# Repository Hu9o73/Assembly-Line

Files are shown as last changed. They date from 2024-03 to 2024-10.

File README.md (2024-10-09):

# Assembly Line

Projet Assembly Line : L'objectif étant de créer une machine fabricant des drones à la chaine.

Note: Par manque de fonds, le projet a été arrêté à la fin de la phase de conception. Le document UROP-PrésentationProjetComplet.pdf recense nos travaux.

Projet réalisé en collaboartion avec Théo Lissarague. Son profil GitHub peut être retrouvé dans la liste des contributeurs au projet.

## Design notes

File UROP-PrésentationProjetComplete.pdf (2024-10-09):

# UROP : Assembly Line

# Introduction

Des élèves du centre d'innovation (DVIC) du Pôle Universitaire Léonard de Vinci, à la Défense, ont pour objectif de développer un essaim de drones volants. Le développement de leur projet avançant à grands pas, ils ont désormais la nécessité de produire massivement leurs appareils.

L'option industrielle classique n'était pas viable. La quantité de drones à produire étant ridicule à l'échelle d'une usine spécialisée, et même si la quantité n'avait pas été un problème, cela aurait coûté très cher. Ils misent alors sur le développement d'une petite chaine de production, interne au centre, qui réduirait les coûts en plus d'être adaptée à leurs problématiques.

C’est pour répondre à ce besoin que nous avons pour objectif de développer une chaîne d'assemblage capable de produire massivement et sans efforts des drones roulants simples. Une fois la technologie développée pour ces drones simples, la chaine d'assemblage servira de base à une seconde version, modifiée pour produire les drones volants de l'essaim.

# Partie 1 : Le Drone

# Conception

Avant de se lancer dans la conception de la chaine d'assemblage, nous devions savoir quoi assembler. Le cahier des charges du drone était relativement court. Il nous fallait un drone roulant autonome dont la surface au sol ne dépassait pas quinze par quinze centimètres.

Les contraintes supplémentaires, nous nous les sommes imposés en pensant à ce que nous imposerait notre chaine d'assemblage.

La complexité d'une chaine d'assemblage varie grandement. En effet, encastrer une pièce dans une autre est simple. Mais si notre système est plus complexe que deux pièces de Lego®, la complexité de la chaine d'assemblage croît de façon exponentielle. Par exemple, l'ajout d'une simple vis peut impliquer la création d'un bras capable de s'aligner sur le pas de vis, poser la vis, puis changer d'outil pour la visser.

Bien que ce soit quelque chose qui est développable, notre mission est de produire des drones simples dans leur conception pour limiter au maximum la complexité de notre chaine d'assemblage. Nos travaux serviront de base pour développer une chaine plus complexe, adaptée aux drones volants.

Ainsi, nous avons fait le choix de limiter à deux le nombre de roues, car moins de roues c'est moins de moteurs, d'électronique et d'encastrements sur la chaine d'assemblage. La stabilité de notre drone sera assurée différemment. De plus, nous avons décidé de nous débarrasser des vis et d'assurer l'intégralité des liaisons par des systèmes de fixation rapide (clips).

Ne visant pas la performance sur ces petits drones, nous n'avons aucunement besoin qu'ils soient rapide. Ainsi, pour les contrôler plus facilement, nous faisons le choix de moteurs pas-à-pas pour actionner les roues, plutôt que les moteurs à courant continu standard. Les moteurs pas-àpas permettent un contrôle très précis en échange d'une vitesse plus lente.

# Electronique et PCB

Sachant dans quelle direction nous allons, nous décidons que le drone serait construit autour de
son PCB (Printed Circuit Board | Circuit Imprimé). Ainsi, nous commençons par cette étape
avec comme objectif de le rendre le plus petit possible.

Le drone serait dans un premier temps contrôlé par une carte de développement de type ESP32. Elles ne sont pas très cher, simple à programmer et s'adaptent largement à nos besoins tout en laissant place à d'éventuelles améliorations du drone par la suite.

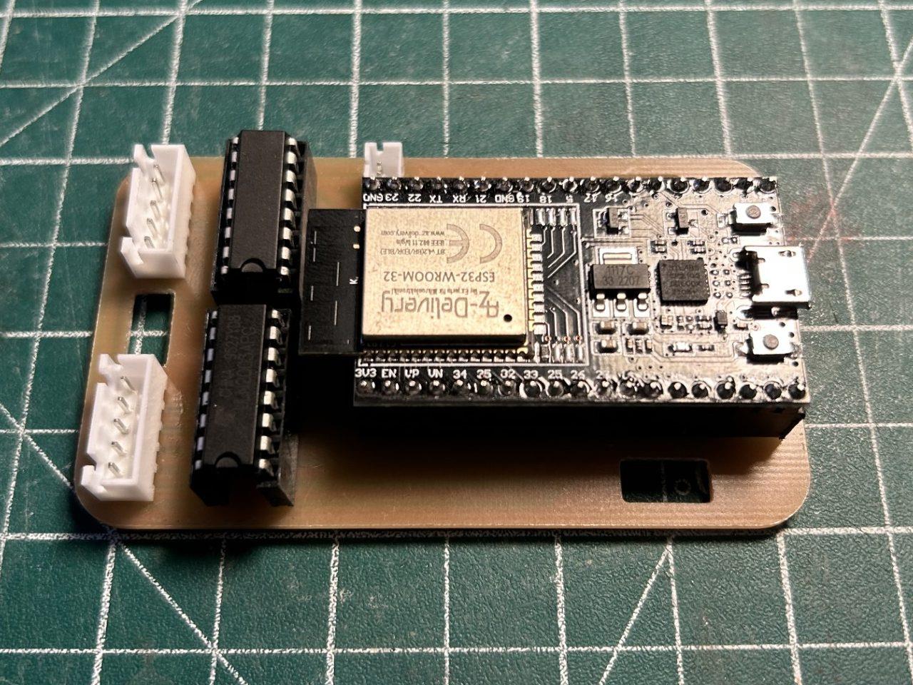
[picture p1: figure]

L'ESP32 (à droite), fixé sur le circuit imprimé de prototypage.

Dans le but de faire le drone le moins cher possible à la production, nous choisissons des moteurs pas-à-pas 28BYJ-48 en 5V. Ce sont les moteurs pas-à-pas de base, ils sont massivement produit, ne coûtent pas cher et sont simple à contrôler. De plus, après quelques tests, nous réalisons qu'ils tournent toujours avec une alimentation de 3.7V.

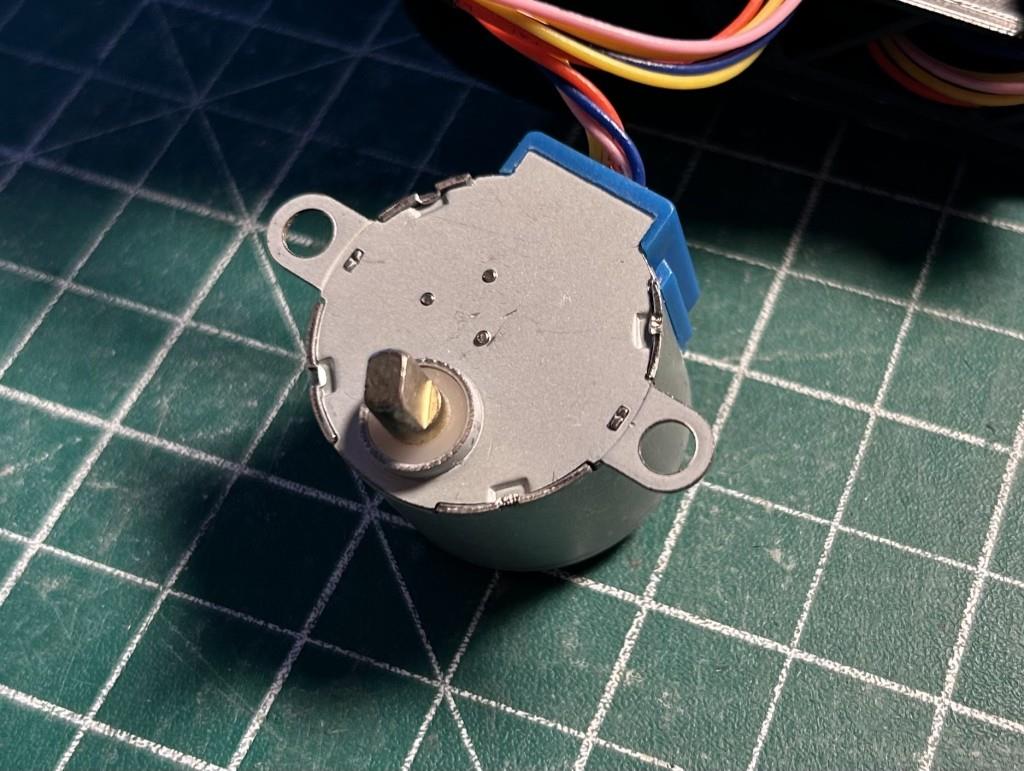
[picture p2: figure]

Un moteur pas-à-pas 28BYJ-48 utilisé sur le drone.

Nous faisons le choix d’alimenter notre drone à l’aide d'une batterie LiPo 3.7V. Nous économisons ainsi sur le plan financier et énergétique. En effet, pour une consommation de x ampères, notre drone sera 25% moins puissant avec une batterie en 3.7V plutôt que 5V, et par conséquent 25% moins énergivore.

Pour les contrôler, ils sont généralement livrés avec des drivers "UNL-2003". Ces derniers mesurent 3 centimètres par 3, il en faut un par moteur et par conséquent il serait bon de pouvoir s'en passer pour gagner de la place.

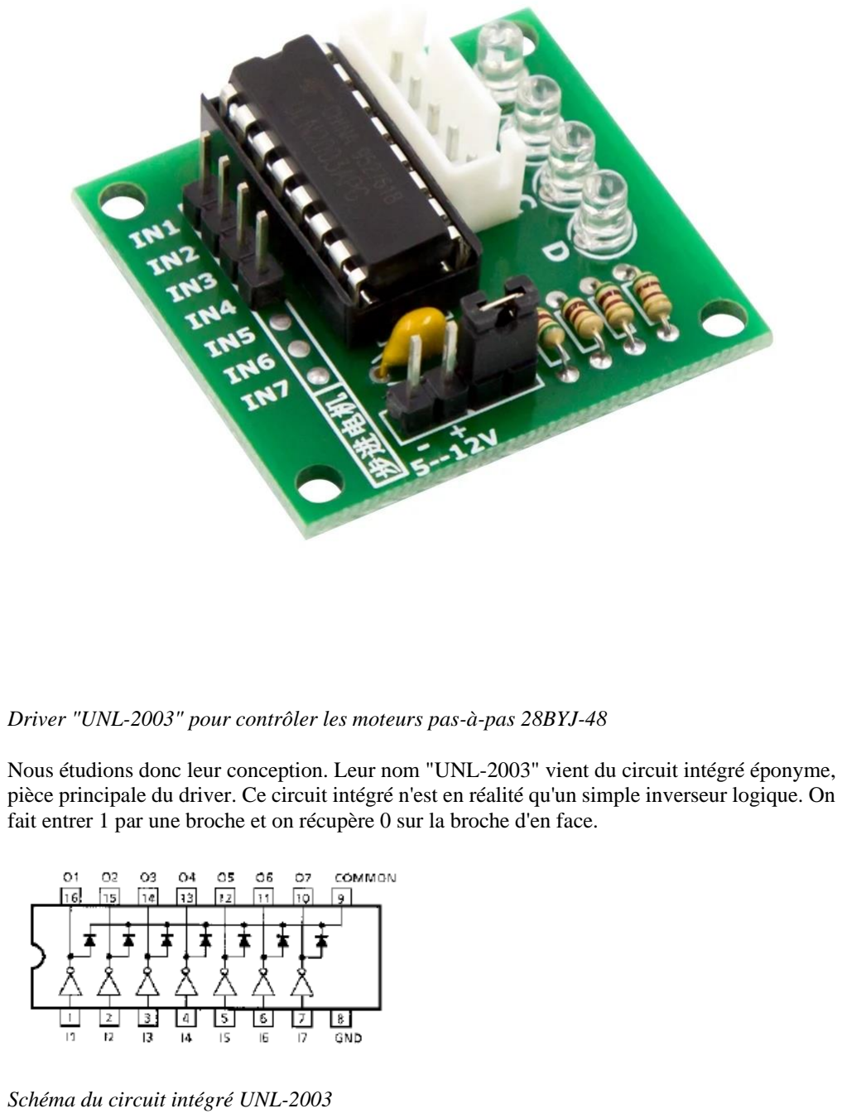
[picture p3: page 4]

Driver "UNL-2003" pour contrôler les moteurs pas-à-pas 28BYJ-48

Nous étudions donc leur conception. Leur nom "UNL-2003" vient du circuit intégré éponyme, pièce principale du driver. Ce circuit intégré n'est en réalité qu'un simple inverseur logique. On fait entrer 1 par une broche et on récupère 0 sur la broche d'en face.

Schéma du circuit intégré UNL-2003

Voyant un circuit intégré si simple, nous nous demandons pourquoi avoir besoin de tout le reste pour que le driver fonctionne. Par une simple étude du circuit imprimé du driver, nous concluons que hors du circuit intégré, le reste de le PCB du driver n'est utile qu'à l'allumage de LEDs pour avoir un retour visuel des ordres de contrôle envoyés au moteur. Nous décidons donc de ne garder de ce driver superflu que le circuit intégré.

Nous n'aurons ainsi qu'à commander les circuits intégrés à quelques centimes l'unité plutôt que le PCB dans son intégralité. Nous simplifions ainsi le circuit de notre drone et une nouvelle fois, nous réalisons des économies financières, de place et énergétiques (suppression des LEDs implique suppression de la consommation liées à ces dernières) !

Notre circuit, désormais simplifié au maximum, ne se résume qu'à une carte de développement ESP32, quelques connecteurs et deux circuits intégrés UNL-2003. Ces derniers ne disposant que de 7 couples de broches entrées/sorties, sachant qu'il en faut 4 par moteur, nous sommes contraints d'en utiliser 2. Remarque nous pourrions à l'avenir, chercher un circuit intégré similaire intégrant plus de broches, mais le drone n'étant pas l'objet principal de notre projet, pour gagner du temps sur le développement de la chaîne de production à proprement parler, nous n'avons pour l'heure pas cherché à l'optimiser à ce point.

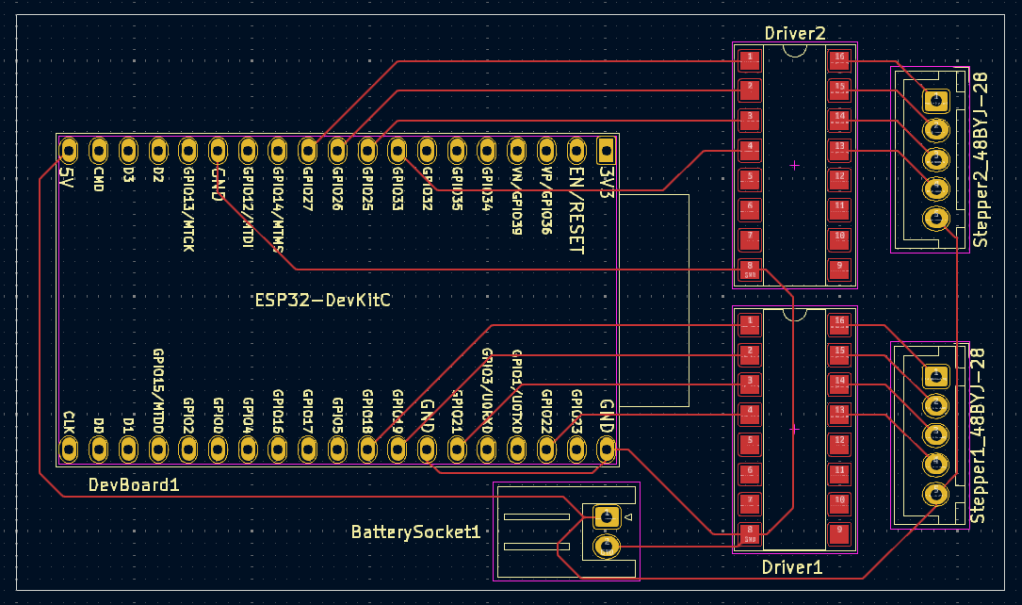
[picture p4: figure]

Schéma du PCB de notre drone : Le schéma du circuit est disponible sur le GitHub (https://github.com/theoliss/assembly_line/tree/main)

# CAD

Une fois le PCB déterminé et dont le prototype ait été fabriqué au sein même du DVIC, nous avons pu nous lancer sur le développement du drone. Pour simplifier l'assemblage nous avons supprimé d'éventuelles vis au profit d'un système d'accroche rapide pour le drone et le PCB et d'encastrement pour les moteurs.

Le drone sera constitué de trois couches. Une base sur laquelle siègent les accroches de notre système de fixation, qui traverseront tout le drone ; un étage intermédiaire destiné au maintien des moteurs latéraux; enfin, un étage supérieur, soutenu par une forêt de supports, sur lequel viendra se fixer notre PCB. La batterie viendra se glisser à l'arrière, dans un emplacement dédié, caché dans la forêt de supports.

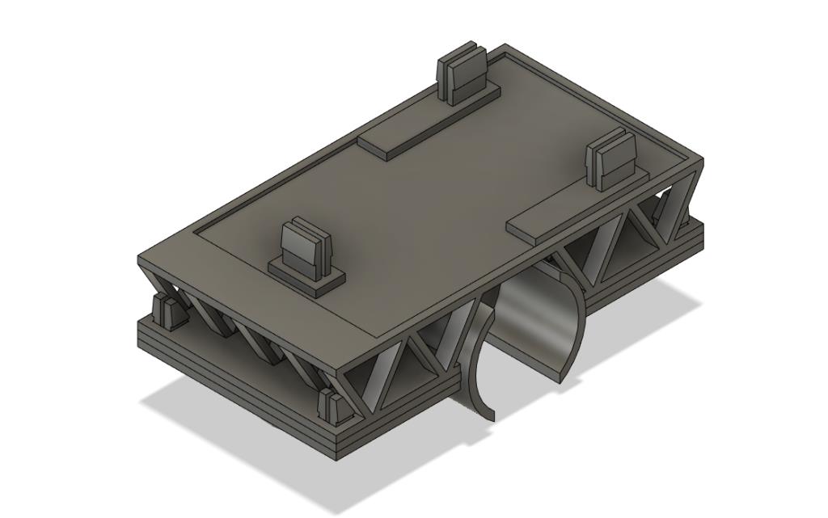
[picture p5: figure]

Structure du drone, les 3 parties assemblées, modélisée sur Fusion360, fichiers disponibles sur le GitHub (https://github.com/theoliss/assembly_line/tree/main)

# Partie 2 : La chaîne d'assemblage

# Conception

Le drone à assembler prêt, nous pouvions nous pencher sur la chaîne d'assemblage en ellemême. Dans un premier temps nous avons pensé à un système de tapis roulant, bacs à pièces et presses pour tout assembler. Cependant l'idée est de toujours penser au plus simple. Le but est de pouvoir adapter notre chaîne à différents types de drones facilement. Ainsi nous nous sommes demandé comment réduire le nombre d'éléments pour faciliter l'adaptabilité.

C'est pourquoi nous nous sommes orientés vers un bras robotisé. Très versatile, il nous permettra de réaliser une floppée de tâches de différentes natures : attraper, poser, enfoncer, visser (soyons fou !).

Pour gagner du temps nous nous sommes basés sur le bras open source de BCN3D, lui-même basé sur un autre bras open source. Après lui avoir apporté quelques modifications pour qu'il réponde à nous besoins, nous l'avons mis sur rail pour ajouter un axe de mobilité, étendant le champ des possibles.

# Le bras

Comme dit plus haut, la base de notre bras est le Moveo de BCN3D (bras open-source) dont voici le GitHub. (https://github.com/BCN3D/BCN3D-Moveo) Après quelques calculs, nous décidons de changer les moteurs pas-à-pas pour des plus puissants, afin qu'il soit en mesure de réaliser les tâches qui lui incomberont. Ce changement impliqua un recalcul de la mécanique du bras, ainsi que de la puissance totale nécessaire pour faire fonctionner la chaîne. (cf. document « CalculsCouples »)

Par la suite, nous avons conçu son rail, le bras se déplaçant latéralement sur environ quatrevingts centimètres, tracté par un moteur pas-à-pas supplémentaire.

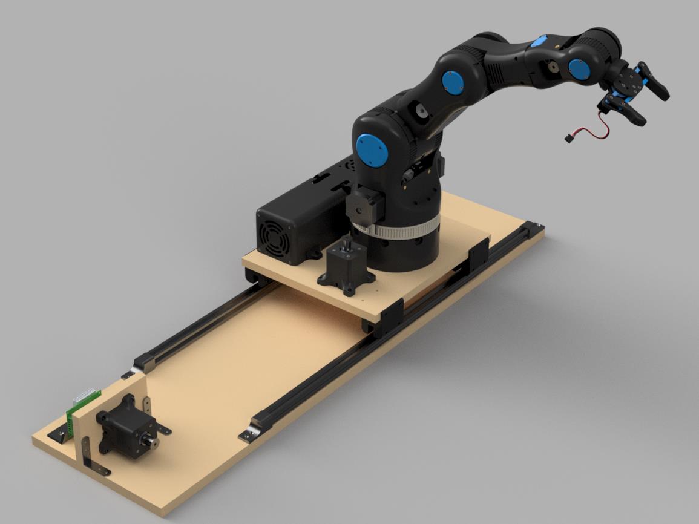
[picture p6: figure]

Le MOVEO modifié sur son rail.

Après avoir effectué les calculs mécaniques et électroniques mentionnés plus haut et disponibles dans des documents PDF sur le GitHub, (https://github.com/theoliss/assembly_line/tree/main) nous jetons nos dévolus sur les moteurs NEMA suivants :

Référence | Type | Couple | Quantité
14HS20-1504S | NEMA 14 | 40 Ncm | 1
17HS13-0404S1 | NEMA 17 | 26 Ncm | 1
17HS19-1684S-PG5 NEMA 17 | Engrenages 5:1 52 Ncm (moteur seul) 1
17HE24-2104S | NEMA 17 | 60 Ncm | 2
23HE22-2804S | NEMA 23 | 126 Ncm | 2

Tableau des moteurs utilisés pour la fabrication du bras.

Concernant l'électronique, le bras sera contrôlé par une carte de développement fonctionnant avec une puce ATMega (un équivalent Arduino MEGA). La carte contrôlera les sept drivers TB6560, le tout étant alimenté par une alimentation de 24V pour 600 watts. Voici un extrait du schéma, le schéma complet et les évaluations de consommation étant disponibles sur le GitHub. (https://github.com/theoliss/assembly_line/tree/main)

Nous sommes ici contraint de changer de drivers car contrairement aux petits moteurs du drone, les NEMA sont des moteurs bien plus puissant. L'intensité nécessaire peut flirter avec les 3 ampères pour les NEMA 23 ! Bien au delà de la limite de l'intensité délivrable par une carte de développement (200mA pour l'Arduino MEGA, soit 15 fois moins). D'où la nécessité de penser à notre alimentation et ses limites, ainsi qu'à la mise en place de drivers adaptés. Ici, les TB6560 sont conçu pour supporter jusqu'à 3A, nous permettant de travailler avec les NEMA 14, 17 et 23 que nous comptons utiliser.

Nous avons choisi les NEMA pour leur rapport qualité/prix et leur disponibilité sur le marché (en plus du fait qu'ils respectent nos contraintes).

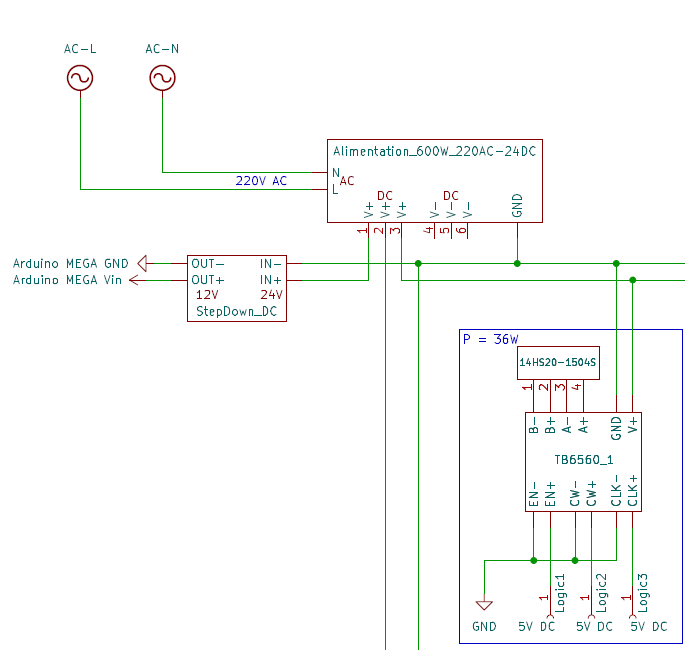
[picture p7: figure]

Extrait du schéma. Les autres blocs moteurs + drivers sont connectés de la même façon, tous en dérivation.

# Sources :

GitHub du projet : GitHub - Assembly Line (https://github.com/theoliss/assembly_line/tree/main)

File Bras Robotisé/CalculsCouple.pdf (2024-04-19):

BONNELL Hugo

# UROP - Assembly Line

### Calculs couples moteurs

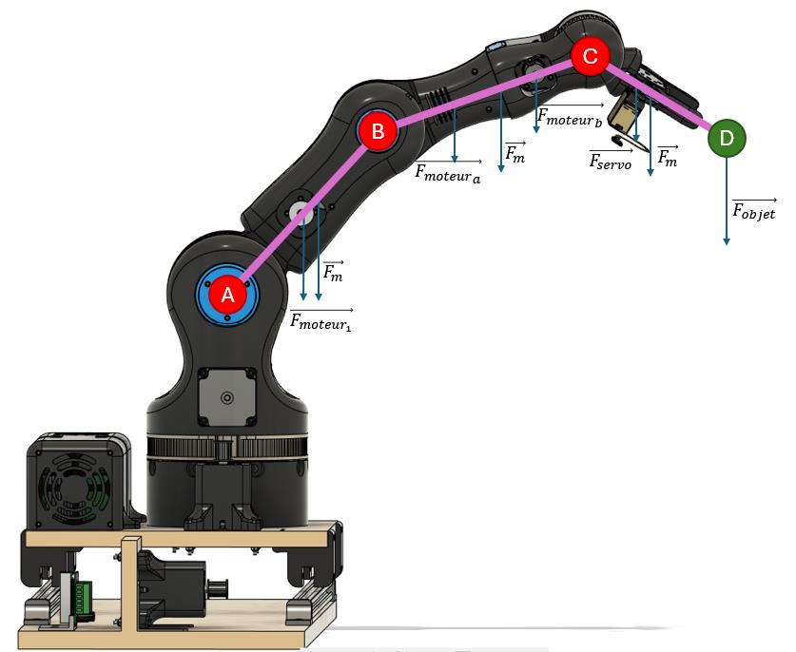
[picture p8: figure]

# Introduction

Ce document recense les calculs effectués pour déterminer les couples nécessaires des moteurs pas-à-pas dans le bras de la chaîne d’assemblage. Pour effectuer ces calculs, nous considérons le bras dans sa position la plus contraignante pour les moteurs, c’est-à-dire complètement « détendu » parallèle au sol.
C’est en effet dans cette position que le couple de maintient des moteurs devra être le plus important pour maintenir le bras dans un état statique.
Si les couples des moteurs dépassent les valeurs trouvées, alors en plus de maintenir le bras statique dans cette position, les moteurs seront également capable d’actionner le bras.
Nous considérons que le bras doit pouvoir manipuler un objet d’un poids de 400g au maximum afin d’avoir une (très) confortable marge pour l’assemblage de notre drone, où de changer l’objet de la chaine d’assemblage plus aisément.

# Section A : Choix des moteurs pas-à-pas

## Schémas :

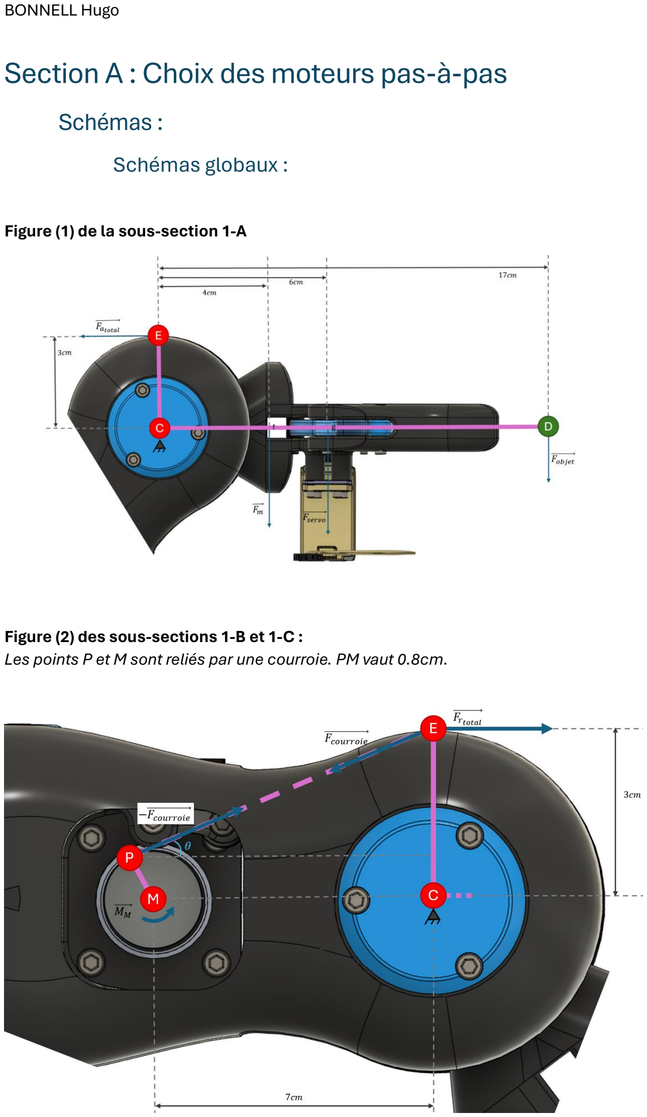
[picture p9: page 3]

### Schémas globaux :

Figure (1) de la sous-section 1-A

Figure (2) des sous-sections 1-B et 1-C :
Les points P et M sont reliés par une courroie. PM vaut 0.8cm.

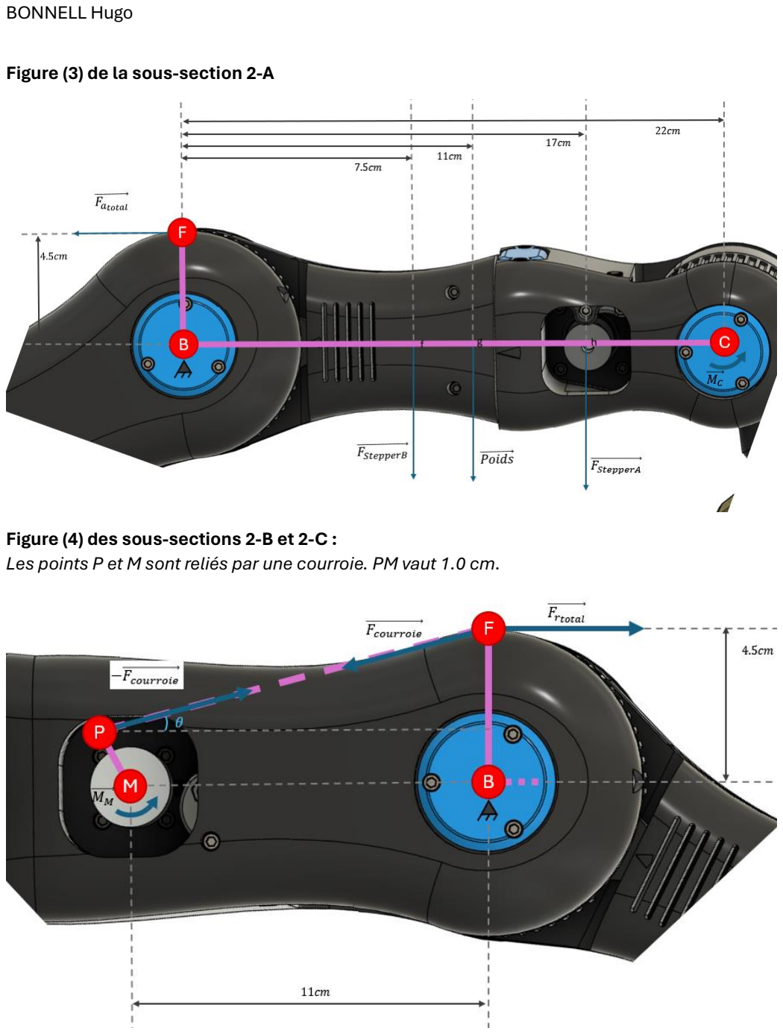
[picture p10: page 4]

Figure (3) de la sous-section 2-A

Figure (4) des sous-sections 2-B et 2-C :
Les points P et M sont reliés par une courroie. PM vaut 1.0 cm.

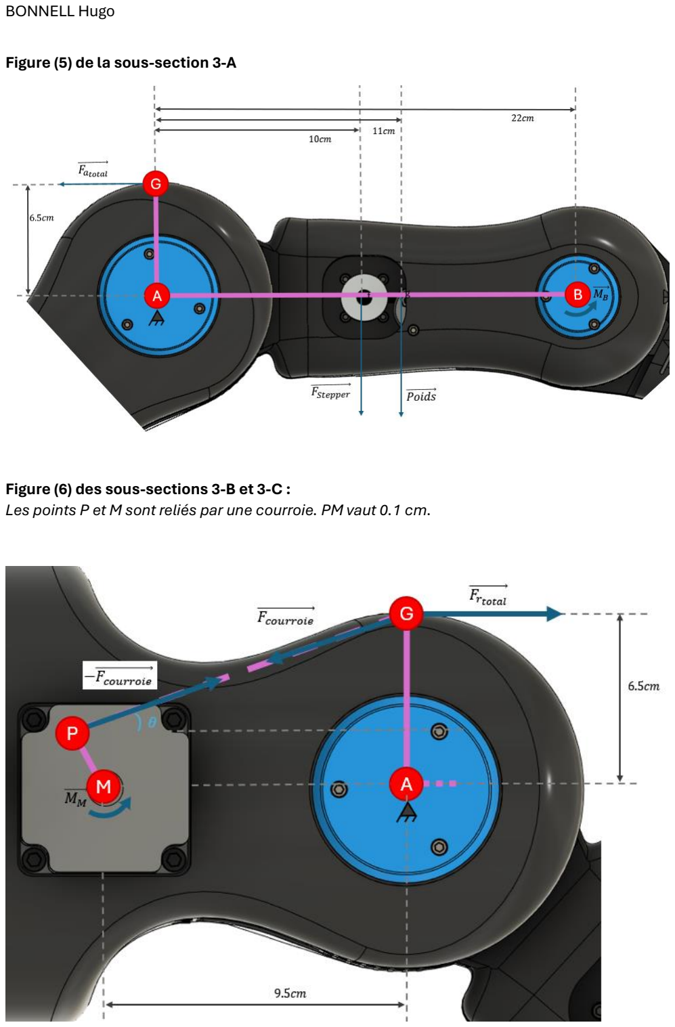
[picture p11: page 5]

Figure (5) de la sous-section 3-A

Figure (6) des sous-sections 3-B et 3-C :
Les points P et M sont reliés par une courroie. PM vaut 0.1 cm.

### Schémas simplifiés :

Figure (7) – Sous-section 1-A

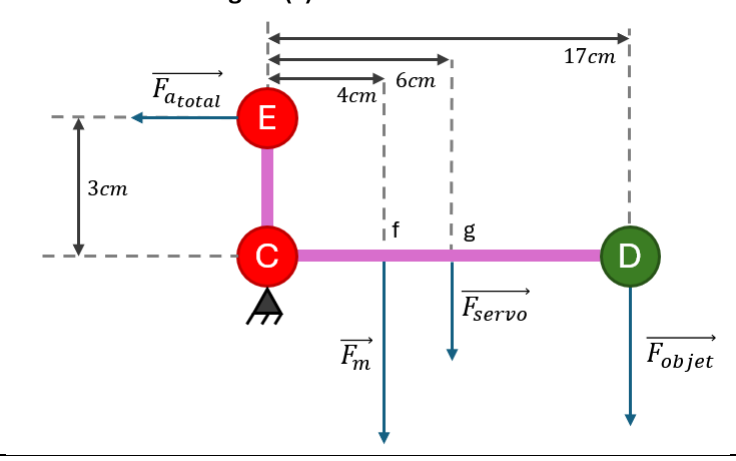
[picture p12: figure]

Figure (8) – Sous-section 1-B

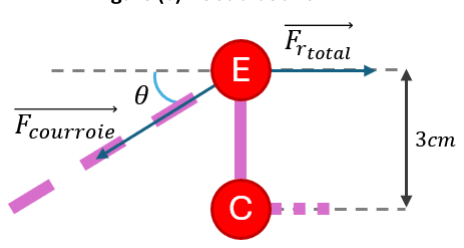
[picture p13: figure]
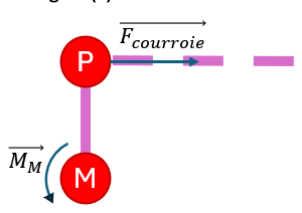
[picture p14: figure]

Figure (9) – Sous-section 1-C

Figure (10) – Sous-section 2-A

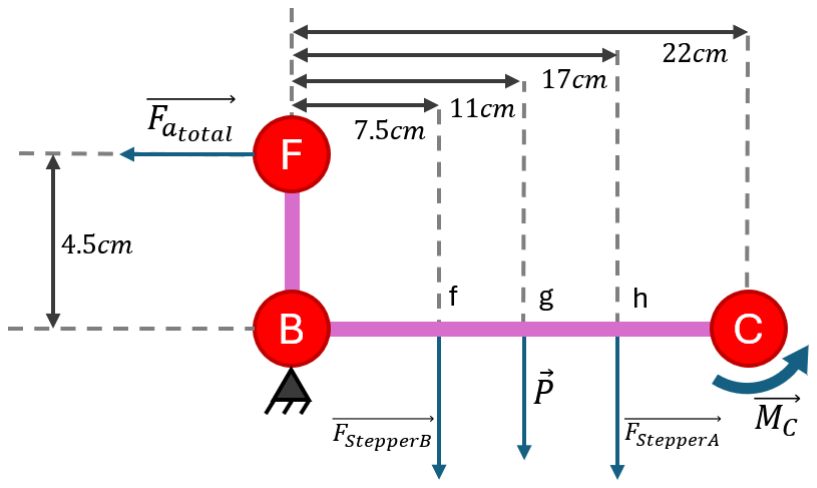
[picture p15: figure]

Figure (11) – Sous-section 2-B

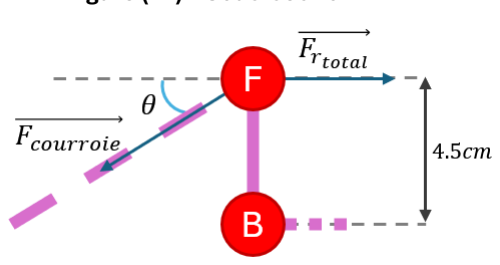
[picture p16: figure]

Figure (12) – Sous-section 2-C

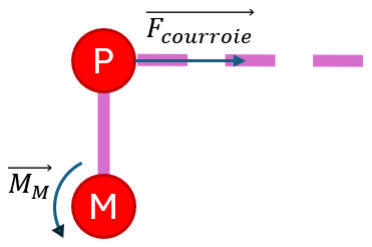
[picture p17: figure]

Figure (13) – Sous-section 3-A

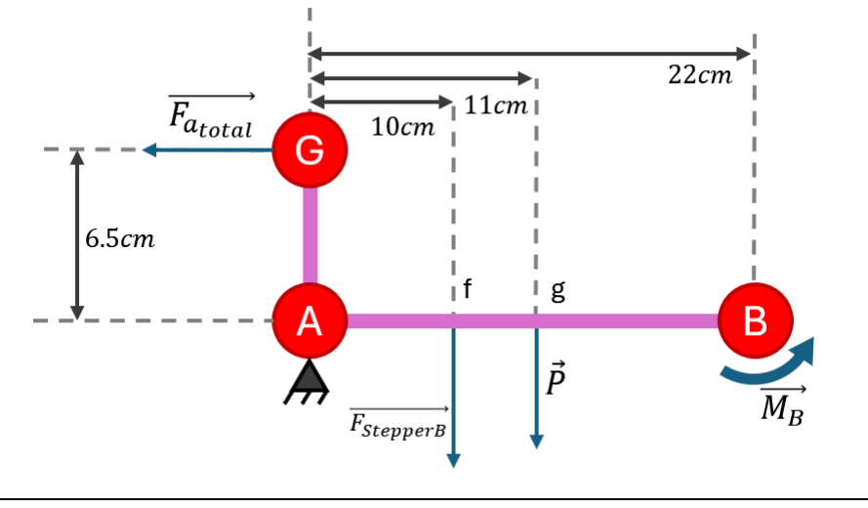
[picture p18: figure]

Figure (14) – Sous-section 3-B

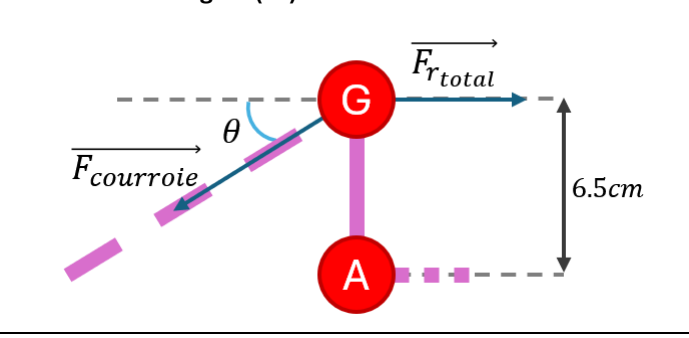
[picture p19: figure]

Figure (15) – Sous-section 3-C

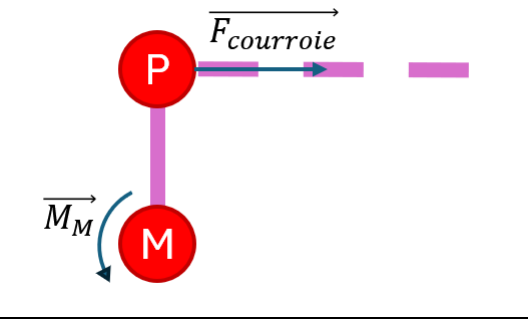
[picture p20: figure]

## Calculs Section 1 :

### Déterminer θ :

Par simple déduction trigonométrique, grâce à la figure (2) on obtient :

θ = arctan (

3 − 0,8
7

) = 0,30 rad

### Déterminer le couple du moteur M de cette section :

En appliquant le théorème des moments statiques :

SOUS-SECTION 1-A :

∑M⃗ (C, Fext ⃗⃗⃗⃗⃗⃗⃗ ) = CE⃗ ∧ Fatotal ⃗⃗⃗⃗⃗⃗⃗⃗ + Cf⃗⃗⃗ ∧ Fm
⃗⃗⃗⃗ + Cg⃗ ∧ Fservo

⃗⃗⃗⃗⃗⃗⃗ + CD⃗⃗⃗ ∧ Fobjet ⃗⃗⃗⃗⃗⃗⃗⃗⃗

- ∑ M⃗ (C, Fext ⃗⃗⃗⃗⃗⃗⃗ ) = 0,03y ∧ (−Fatotal)x + 0,04x ∧ (−Fm)y + 0,06x ∧ (−Fservo)y + 0,17x × (−Fobjet)y
- 0,03Fatotal = (0,04 × 0,150 + 0,06 × 0,060 + 0,17 × 0,400) × 9,81
- Fatotal ≅ 25N
SOUS-SECTION 1-B :

Sachant ‖Fatotal

⃗⃗⃗⃗⃗⃗⃗⃗⃗⃗ ‖ = ‖Frtotal

⃗⃗⃗⃗⃗⃗⃗ ‖ :

∑M⃗ (C, Fext ⃗⃗⃗⃗⃗⃗⃗ ) = CE⃗ ∧ Frtotal ⃗⃗⃗⃗⃗⃗⃗⃗⃗⃗⃗⃗ + CE⃗ ∧ Fcouroie ⃗⃗⃗⃗⃗⃗⃗⃗⃗⃗

- ∑ M⃗ (C, Fext ⃗⃗⃗⃗⃗⃗⃗ ) = 0,03y ∧ Frtotal

⃗⃗⃗⃗⃗⃗⃗⃗⃗⃗⃗⃗ + 0,03y ∧ Fcouroie

⃗⃗⃗⃗⃗⃗⃗⃗⃗⃗

- ∑ M⃗ (C, Fext ⃗⃗⃗⃗⃗⃗⃗ ) = 0,03y ∧ Frtotal

⃗⃗⃗⃗⃗⃗⃗⃗⃗⃗⃗ + 0,03y ∧ (

− cos(θ)Fcouroie

− sin(θ)Fcouroie
0

)

- ∑ M⃗ (C, Fext ⃗⃗⃗⃗⃗⃗⃗ ) = 0,03y ∧ (

Frtotal
0
0

) + 0,03y ∧ (

− cos(θ)Fcouroie

− sin(θ) Fcouroie
0

)

- ∑ M⃗ (C, Fext ⃗⃗⃗⃗⃗⃗⃗ ) = (−0,03 × Frtotal + 0,03 × cos(θ) Fcouroie)z

Or : ∑ M⃗ (C, Fext ⃗⃗⃗⃗⃗⃗⃗ ) = 0 d’où: Frtotal = cos(θ) Fcouroie (= Fatotal) Fcouroie =

Fatotal
cos(θ)
SOUS-SECTION 1-C :

∑M⃗ (M, Fext ⃗⃗⃗⃗⃗⃗ ) = MM ⃗⃗⃗⃗ + MP ⃗⃗⃗ ∧ Fcouroie

⃗⃗⃗⃗⃗⃗⃗⃗⃗⃗⃗⃗ = 0

|MM

⃗⃗⃗⃗⃗⃗ | = |0,008x ∧

Fatotal
cos(θ)
y | = 0,008 ×

25
cos (0,300 rad)

= 0,21 Nm

## Choix du moteur Section 1 :

Pour maintenir un objet de 400g il nous faudrait un moteur de couple 21 Ncm. Ainsi, si nous voulons le soulever, on déduit qu’il nous faut un moteur plus puissant que 21Ncm.
Nos contraintes pour ce moteur deviennent les suivantes :
Type : | Moteur pas-à-pas
Dimensions (L*l*h) : | 35mm * 35mm * ∞ | Format NEMA14
Couple : | Min : 21N ∙ cm

On choisira donc le moteur suivant :
Type : | Pas-à-pas | NEMA 14
Référence : | 14HS20-1504S
Couple : | 40 N × cm
Poids : | 0.35kg
Tension nominale : | 4.2 V
Intensité par phase : | 1.5 A
Résistance/phase : | 2.8 ohms
Dimensions : | 35mm*35mm*52mm
Diamètre de l’arbre : | 5mm
Pas : | 1,8°
Connexions : | A+ | Noir A- | Vert B+ | Rouge B- | Bleu
Revendeur : | StepperOnline
Lien : | https://www.omc-stepperonline.com/fr/nema-14-bipolaire-1-8deg-40ncm-56-7oz-in-1-5a-4-2v-35x35x52mm-4-fils-14hs20-1504s

Note : Il existe un autre modèle de NEMA14 ayant pour couple 23Ncm. Par sécurité, il vaut mieux prendre de la marge en prenant le modèle du dessus (celui choisi).

## Calculs Section 2 :

### Déterminer θ :

Par simple déduction trigonométrique, grâce à la figure (4) on obtient :

θ = arctan (

4.5 − 1.0
11 ) = 0,308 rad

### Déterminer le couple du moteur M de cette section :

En appliquant le théorème des moments statiques : SOUS-SECTION 2-A :

∑M⃗ (B, Fext ⃗⃗⃗⃗⃗⃗⃗ ) = BF⃗ | ∧ Fatotal
⃗⃗⃗⃗⃗⃗⃗⃗⃗⃗⃗⃗ + Bf⃗ ∧ FStepperB ⃗⃗⃗⃗⃗⃗⃗⃗⃗⃗⃗⃗⃗⃗⃗⃗ + Bg⃗ | ∧ P⃗ + B⃗ℎ ∧ FStepperA ⃗⃗⃗⃗⃗⃗⃗⃗⃗⃗⃗⃗⃗⃗ + Mc
⃗
- ∑ M⃗ (B, Fext ⃗⃗⃗⃗⃗⃗⃗ ) = 0,045y ∧ (−Fatotal)x + 0,075x ∧ (−0,300 × 9,81)y + 0,11x ∧ (−0,200 × 9,81)y + 0,17x ∧ (−0,350 × 9,81)y + (0,26 × 0,150 + 0,28 × 0,060 + 0,39 × 0,400) × 9,81
- 0,045Fatotal = 0,075 × 2,943 + 0,11 × 1,962 + 0,17 × 3,4335 + 2,08 = 3,1
- Fatotal ≅ 69N
SOUS-SECTION 2-B :

Sachant ‖Fatotal

⃗⃗⃗⃗⃗⃗⃗⃗⃗⃗ ‖ = ‖Frtotal

⃗⃗⃗⃗⃗⃗⃗ ‖ :

∑M⃗ (B, Fext ⃗⃗⃗⃗⃗⃗⃗ ) = BF⃗ | ∧ Frtotal
⃗⃗⃗⃗⃗⃗⃗⃗⃗⃗⃗⃗ + BF⃗ | ∧ Fcouroie

⃗⃗⃗⃗⃗⃗⃗⃗⃗⃗⃗

- ∑ M⃗ (B, Fext ⃗⃗⃗⃗⃗⃗⃗ ) = 0,045y ∧ Frtotal

⃗⃗⃗⃗⃗⃗⃗⃗⃗⃗⃗⃗ + 0,045y ∧ Fcouroie

⃗⃗⃗⃗⃗⃗⃗⃗⃗⃗⃗⃗

- ∑ M⃗ (B, Fext ⃗⃗⃗⃗⃗⃗⃗ ) = 0,045y ∧ Frtotal

⃗⃗⃗⃗⃗⃗⃗⃗⃗⃗⃗ + 0,045y ∧ (

− cos(θ) Fcouroie

− sin(θ) Fcouroie
0

)

- ∑ M⃗ (B, Fext ⃗⃗⃗⃗⃗⃗⃗ ) = 0,045y ∧ (

Frtotal
0
0

) + 0,045y ∧ (

− cos(θ) Fcouroie

− sin(θ)Fcouroie
0

)

- ∑ M⃗ (B, Fext ⃗⃗⃗⃗⃗⃗⃗ ) = (−0,045 × Frtotal + 0,045 × cos(θ) Fcouroie)z

Or : ∑ M⃗ (B, Fext ⃗⃗⃗⃗⃗⃗⃗ ) = 0 d’où: Frtotal = cos(θ) Fcouroie (= Fatotal) Fcouroie =

Fatotal
cos(θ)
SOUS-SECTION 2-C :

∑M⃗ (M, Fext ⃗⃗⃗⃗⃗⃗ ) = MM ⃗⃗⃗⃗ + MP ⃗⃗⃗ ∧ Fcouroie

⃗⃗⃗⃗⃗⃗⃗⃗⃗⃗⃗⃗ = 0

|MM

⃗⃗⃗⃗⃗⃗ | = |0,01x ∧

Fatotal
cos(θ)
y | = 0,01 ×

69
cos (0,308 rad)

= 0,72 Nm

## Choix du moteur Section 2 :

Nos contraintes pour ce moteur deviennent les suivantes :
Type : | Moteur pas-à-pas
Dimensions (L*l*h) : | 42mm * 42mm * 48mm | Format NEMA17
Couple : | Min : 72 N ∙ cm

On choisira donc le moteur suivant (moteur à engrenages !) :
Type : | Pas-à-pas | NEMA 17
Référence : | 17HS19-1684S-PG5
Couple avant boite d’engrenages : | 52 N × cm
Rapport de la boite d’engrenages : | 5.18 : 1
Couple de sortie : | 242 N ∙ cm
Poids : | 0.52kg
Tension nominale : | 3 V
Intensité par phase : | 1.68 A
Résistance/phase : | 1.8 ohms
Dimensions : | 42mm*42mm*48mm
Diamètre de l’arbre : | 8mm
Pas : | 0,35°
Connexions : | A+ | Noir A- | Vert B+ | Rouge B- | Bleu
Revendeur : | StepperOnline
Lien : | https://www.omc-stepperonline.com/fr/nema-17-moteur-pas-a-pas-bipolaire-l-48mm-w-rapport-d-engrenage-5-1-boite-de-vitesses-planetaire-17hs19-1684s-pg5

Note :
Les moteurs NEMA 17 n’atteignant pas un couple suffisant, nous nous rabattons sur un pas-àpas avec système d’engrenages. En réduisant ainsi la vitesse de rotation, nous augmentons le couple.
Bien que ce modèle ait un couple dépassant largement notre besoin, il remplit notre critère de dimension (Format NEMA 17 et 48mm de profondeur) et de couple.

## Calculs Section 3 :

### Déterminer θ :

Par simple déduction trigonométrique, grâce à la figure (6) on obtient :

θ = arctan (

6.5 − 1
9,5

) = 0,525 rad

### Déterminer le couple du moteur M de cette section :

En appliquant le théorème des moments statiques : SOUS-SECTION 3-A :

∑M⃗ (A, Fext ⃗⃗⃗⃗⃗⃗⃗ ) = AG⃗ ∧ Fatotal ⃗⃗⃗⃗⃗⃗⃗ + Af⃗ ∧ FStepper ⃗⃗⃗⃗⃗⃗⃗⃗⃗⃗ + Ag⃗ ∧ P⃗ + Mc ⃗

- ∑ M⃗ (A, Fext ⃗⃗⃗⃗⃗⃗⃗ ) = 0,065y ∧ (−Fatotal)x + 0,1x ∧ (−0,520 × 9,81)y + 0,11x ∧
(−0,200 × 9,81)y + (0,48 × 0,150 + 0,50 × 0,060 + 0,61 × 0,400 + 0,295 × 0,300 + 0,33 × 0,200 + 0,39 × 0,350) × 9,81
- 0,065Fatotal = 0,1 × 5,10 + 0,11 × 1,962 + 6,25 ≅ 7,0
- Fatotal ≅ 108N
SOUS-SECTION 3-B :

Sachant ‖Fatotal

⃗⃗⃗⃗⃗⃗⃗⃗⃗⃗ ‖ = ‖Frtotal

⃗⃗⃗⃗⃗⃗⃗ ‖ :

∑M⃗ (A, Fext ⃗⃗⃗⃗⃗⃗⃗ ) = AG⃗ | ∧ Frtotal
⃗⃗⃗⃗⃗⃗⃗⃗⃗⃗⃗⃗ + AG⃗ | ∧ Fcouroie
⃗⃗⃗⃗⃗⃗⃗⃗⃗⃗
- ∑ M⃗ (A, Fext ⃗⃗⃗⃗⃗⃗⃗ ) = 0,065y ∧ Frtotal

⃗⃗⃗⃗⃗⃗⃗⃗⃗⃗⃗⃗ + 0,065y ∧ Fcouroie

⃗⃗⃗⃗⃗⃗⃗⃗⃗⃗

- ∑ M⃗ (A, Fext ⃗⃗⃗⃗⃗⃗⃗ ) = 0,065y ∧ Frtotal

⃗⃗⃗⃗⃗⃗⃗⃗⃗⃗⃗ + 0,065y ∧ (

− cos(θ)Fcouroie

− sin(θ) Fcouroie
0

)

- ∑ M⃗ (A, Fext ⃗⃗⃗⃗⃗⃗⃗ ) = 0,065y ∧ (

Frtotal
0
0

) + 0,065y ∧ (

− cos(θ) Fcouroie

− sin(θ) Fcouroie
0

)

- ∑ M⃗ (A, Fext ⃗⃗⃗⃗⃗⃗⃗ ) = (−0,065 × Frtotal + 0,065 × cos(θ)Fcouroie)z

Or : ∑ M⃗ (A, Fext ⃗⃗⃗⃗⃗⃗⃗ ) = 0 d’où: Frtotal = cos(θ)Fcouroie (= Fatotal) Fcouroie =

Fatotal
cos(θ)
SOUS-SECTION 3-C :

∑M⃗ (M, Fext ⃗⃗⃗⃗⃗⃗ ) = MM ⃗⃗⃗⃗ + MP ⃗⃗⃗ ∧ Fcouroie

⃗⃗⃗⃗⃗⃗⃗⃗⃗⃗⃗⃗ = 0

|MM

⃗⃗⃗⃗⃗⃗ | = |0,008x ∧

Fatotal
cos(θ)
y | = 0,01 ×

108
cos (0,525 rad)

= 1.25 Nm

## Choix du moteur Section 3 :

Nos contraintes pour ce moteur deviennent les suivantes :
Type : | Moteur pas-à-pas
Dimensions (L*l*h) : | 57mm * 57mm * ∞ | Format NEMA23
Couple : | Min : 125 N ∙ cm

Les moteurs NEMA 17 n’atteignent pas un couple de 125 N ∙ cm. Ainsi, nous allons en installer deux, fonctionnant face à face et de façon symétrique pour additionner leurs couples. Ainsi, nous cherchons deux exemplaires d’un moteur NEMA 23 de couple 62,5 N ∙ cm au minimum !

Type : | Pas-à-pas | NEMA 23
Référence : | 23HE22-2804S
Couple : | 126 N × cm
Poids : | 0.70 kg
Tension nominale : | 2.52 V
Intensité par phase : | 2.8 A
Résistance/phase : | 0.9 ohms
Dimensions : | 57mm*57mm*56mm
Diamètre de l’arbre : | 6.35mm
Pas : | 1,8°
Connexions : | A+ | Noir A- | Vert B+ | Rouge B- | Bleu
Revendeur : | StepperOnline
Lien : | https://www.omc-stepperonline.com/fr/e-serie-nema-23-moteur-pas-a-pas-bipolar-1-8deg-1-26-nm-178-04oz-in-2-8a-57x57x56mm-4-fils-23he22-2804s

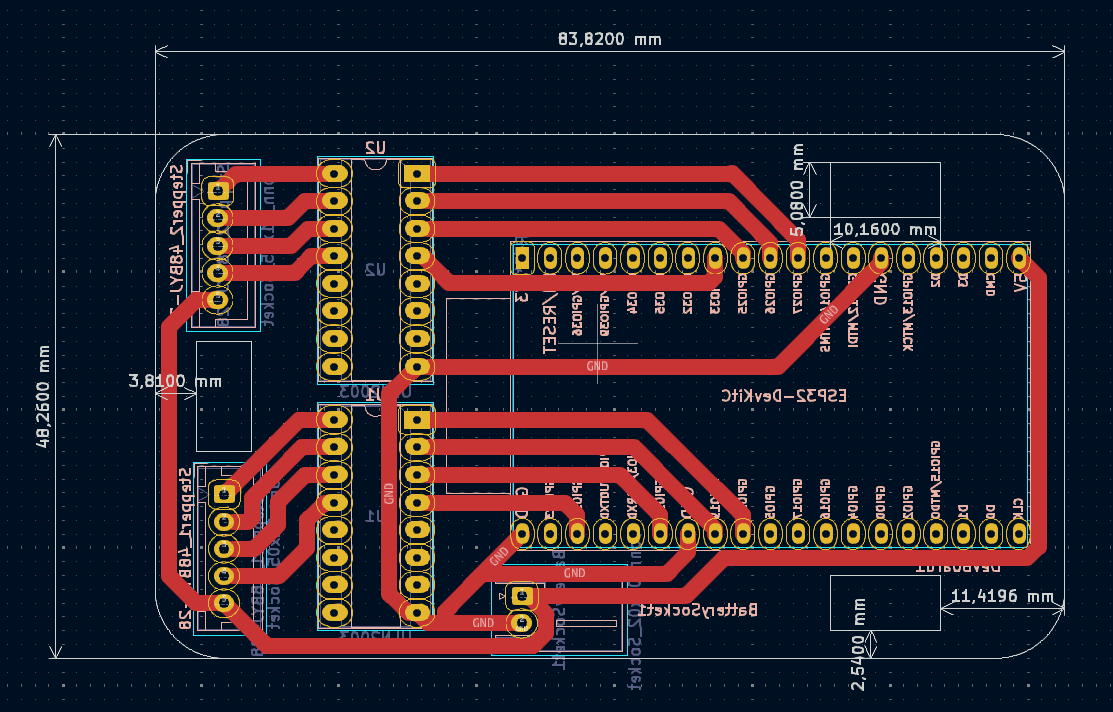
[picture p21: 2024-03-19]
Drone/Electronique/PDF et images/screen_PCB_Drone_THT.png

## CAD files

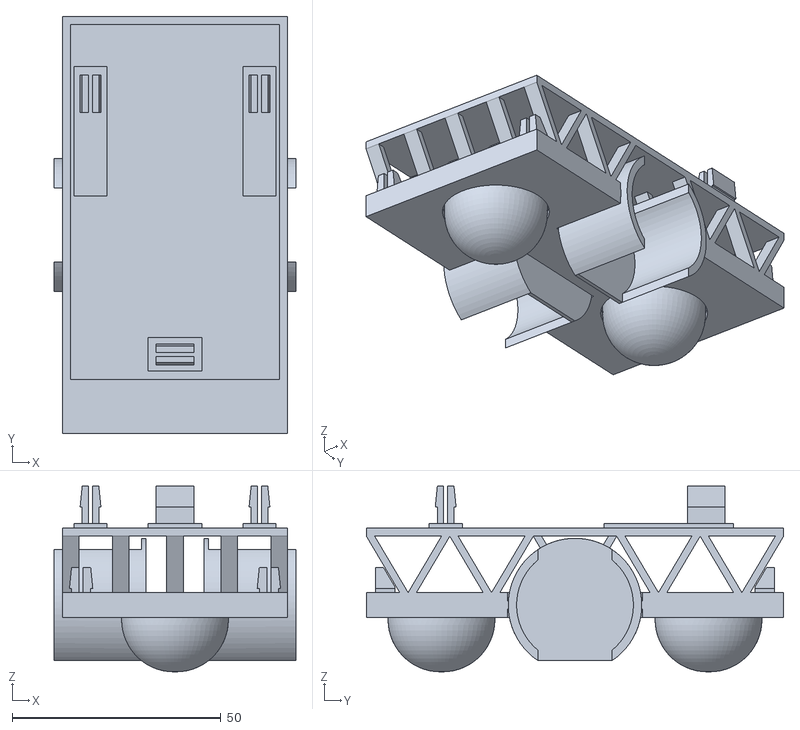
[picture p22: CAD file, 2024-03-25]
Drone/CAD/CAD_Drone/DroneFull.stl
58.0 x 100.0 x 44.5

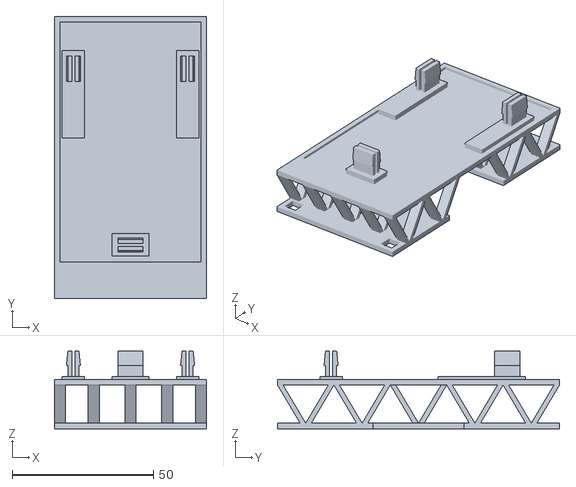
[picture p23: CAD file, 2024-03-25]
Drone/CAD/CAD_Drone/DroneTop.stl
54.0 x 100.0 x 27.5

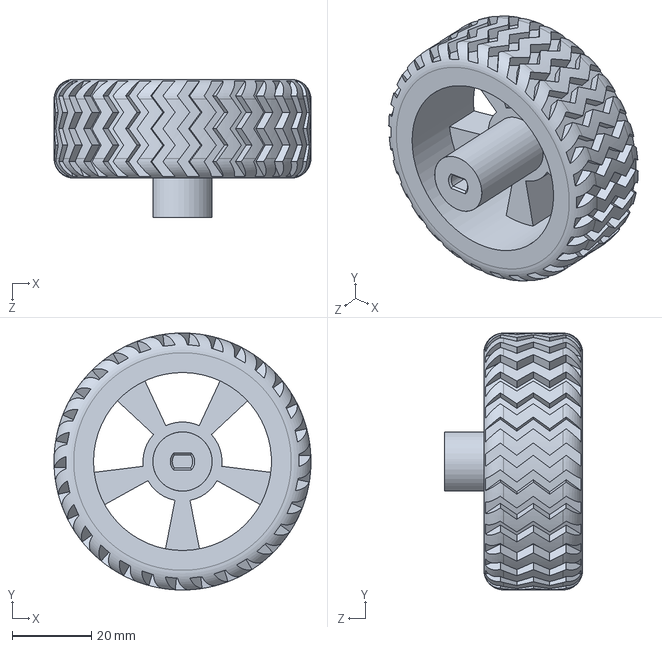
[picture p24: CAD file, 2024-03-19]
Drone/CAD/Roues.SLDPRT
65.0 x 65.0 x 35.0 mm

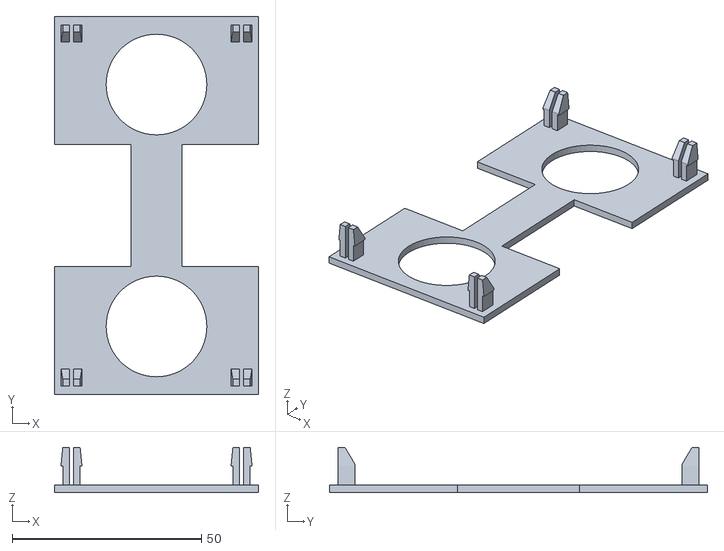
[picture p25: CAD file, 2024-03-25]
Drone/CAD/CAD_Drone/DroneBase.stl
54.0 x 100.0 x 12.0

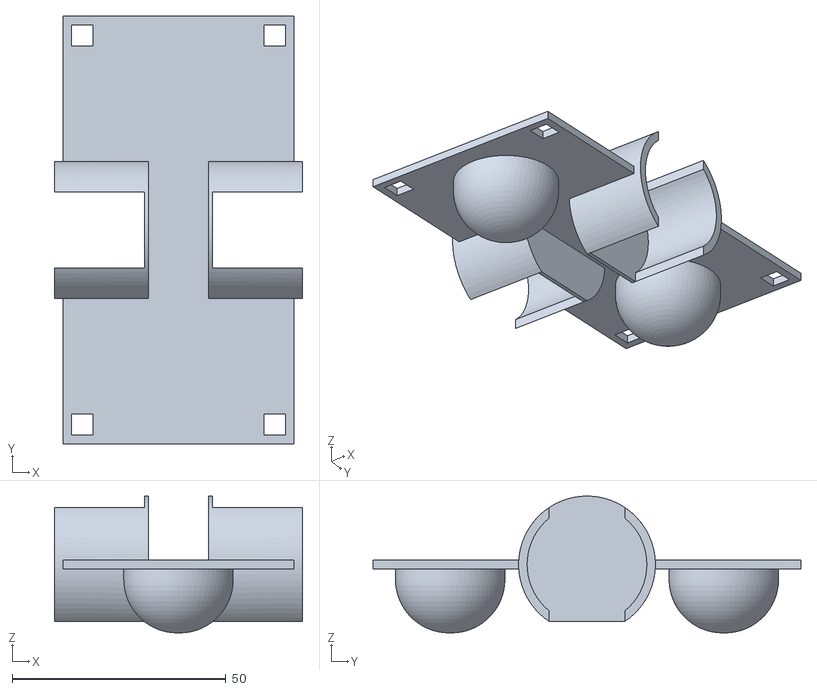
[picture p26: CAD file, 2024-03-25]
Drone/CAD/CAD_Drone/DroneCenter.stl
58.0 x 100.0 x 32.0

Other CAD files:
Drone/CAD/CAD_Drone/DroneFull.f3d
Drone/CAD/Roues.STL

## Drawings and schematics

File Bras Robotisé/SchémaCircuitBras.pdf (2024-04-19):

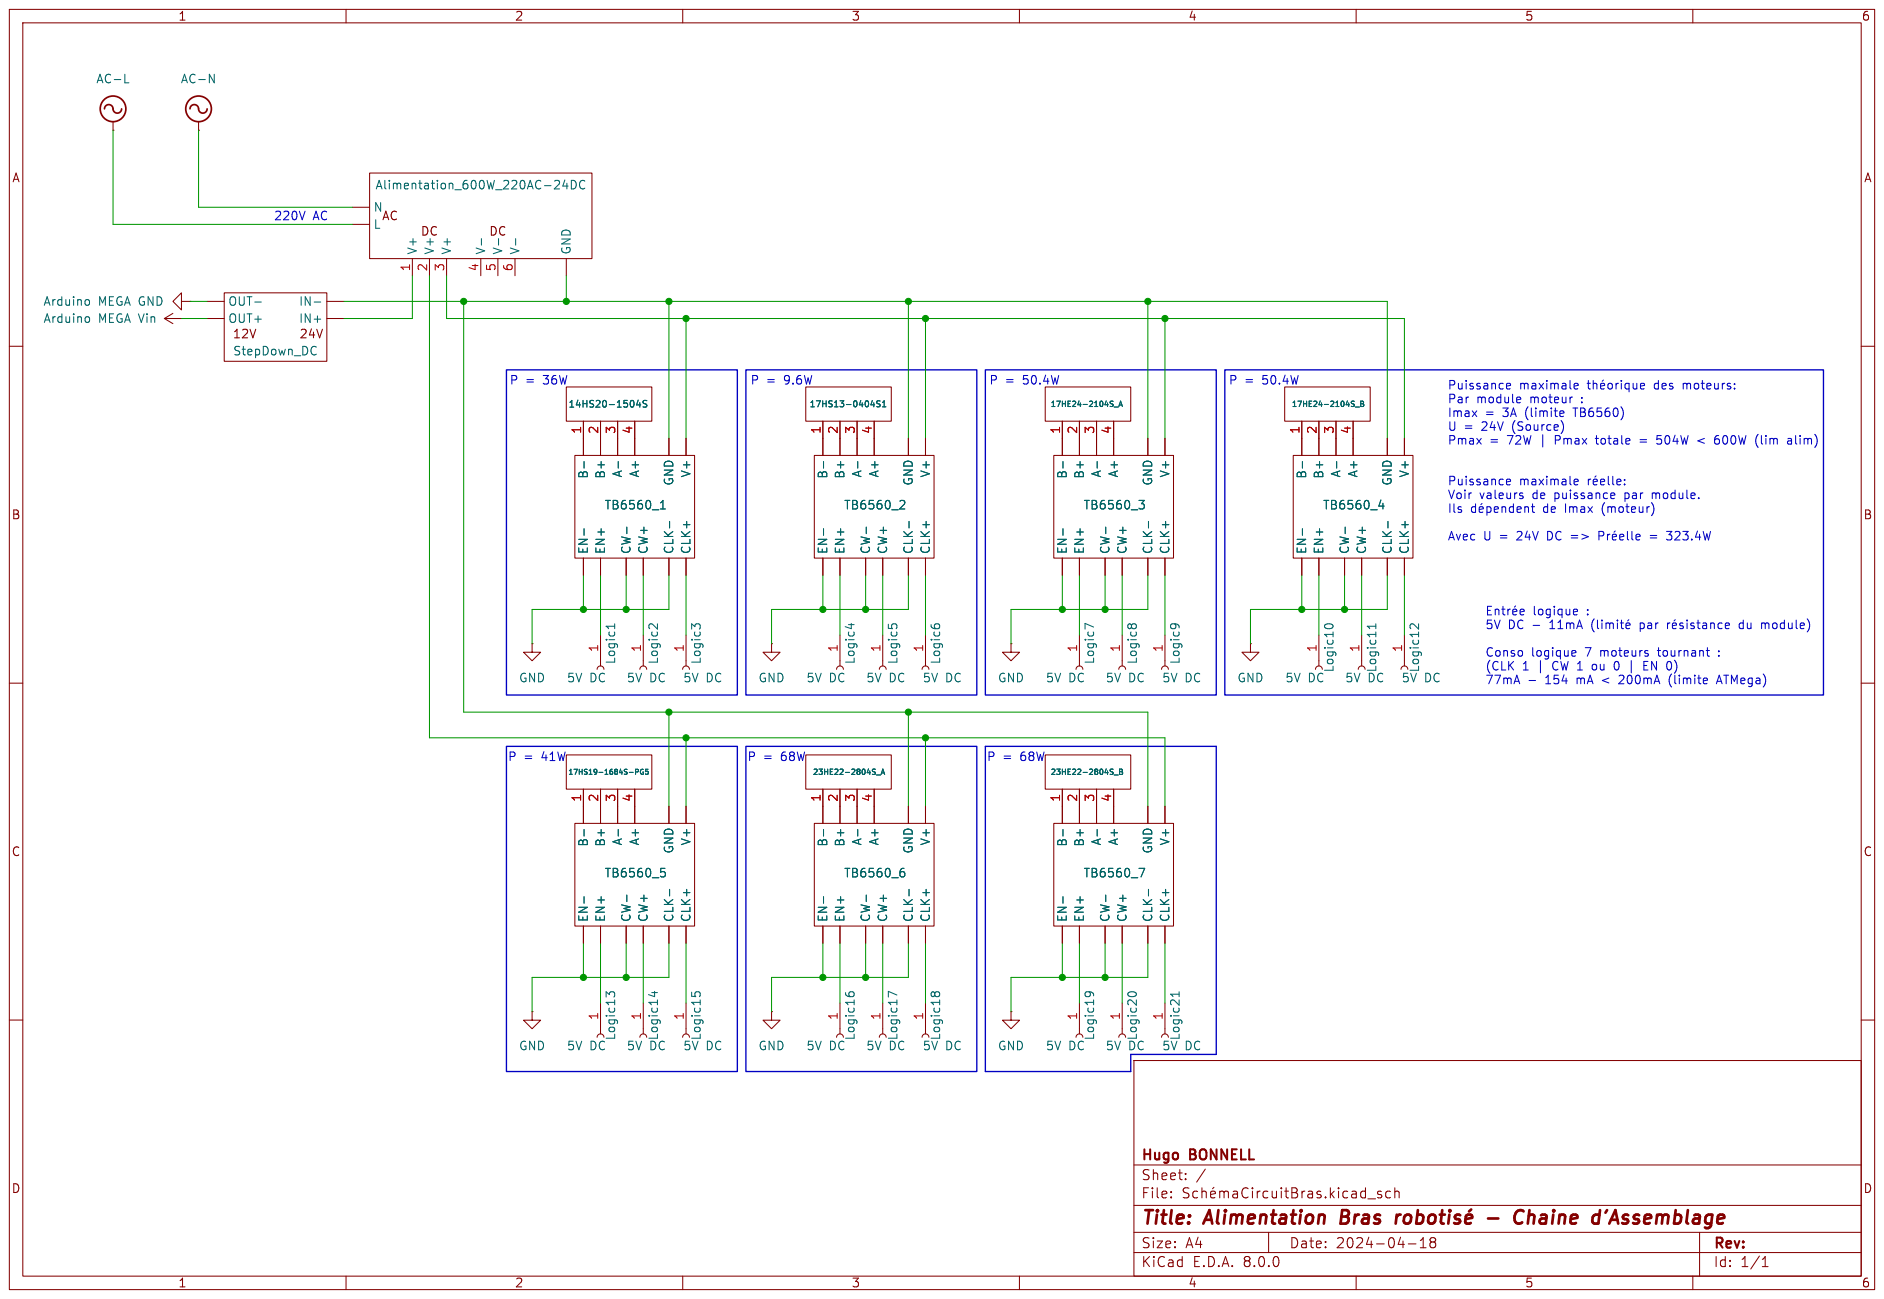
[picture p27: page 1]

3 V- 4 V- 5 V- 6 Alimentation_600W_220AC-24DC B- B+A- A+ EN- EN+ CW- CW+ CLK- CLK+ GNDV+ TB6560_2

4 TB6560_2 B- B+A- A+ EN- EN+ CW- CW+ CLK- CLK+ GNDV+

4 TB6560_4 B- B+A- A+ EN- EN+ CW- CW+ CLK- CLK+ GNDV+

Ils þÿdépendent de Imax (moteur) Avec U = 24V DC => þÿPréelle = 323.4W

4 TB6560_6 B- B+A- A+ EN- EN+ CW- CW+ CLK- CLK+ GNDV+

4 TB6560_7 B- B+A- A+ EN- EN+ CW- CW+ CLK- CLK+ GNDV+

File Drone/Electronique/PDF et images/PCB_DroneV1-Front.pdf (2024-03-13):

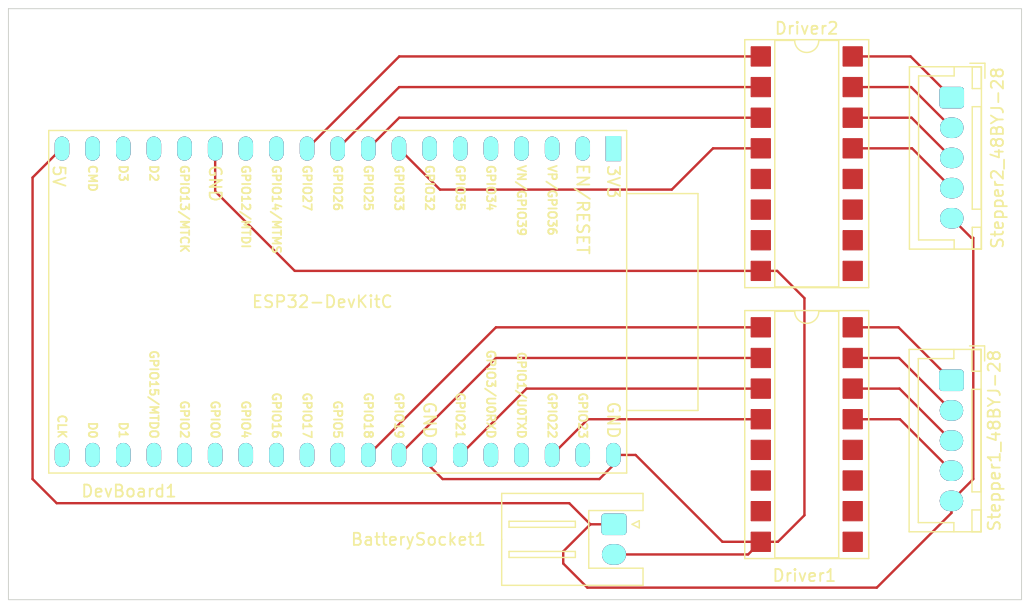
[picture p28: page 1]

Stepper2_48BYJ-28 Stepper1_48BYJ-28 Driver2 Driver1 DevBoard1 ESP32-DevKitC GPIO0 GPIO14/MTMS GPIO18 CMD GPIO26 GPIO3/U0RXDD0 GPIO21 D3 GPIO12/MTDI CLK GPIO23 GPIO27 GPIO4 GPIO5 5VGPIO33 GPIO34 GPIO16 GPIO25 GPIO17 GPIO35 VP/GPIO36 EN/RESET GPIO19 GPIO15/MTDO GND 3V3 GND D2 GPIO1/U0TXD GND GPIO32 GPIO22 GPIO13/MTCK VN/GPIO39 GPIO2D1 BatterySocket1

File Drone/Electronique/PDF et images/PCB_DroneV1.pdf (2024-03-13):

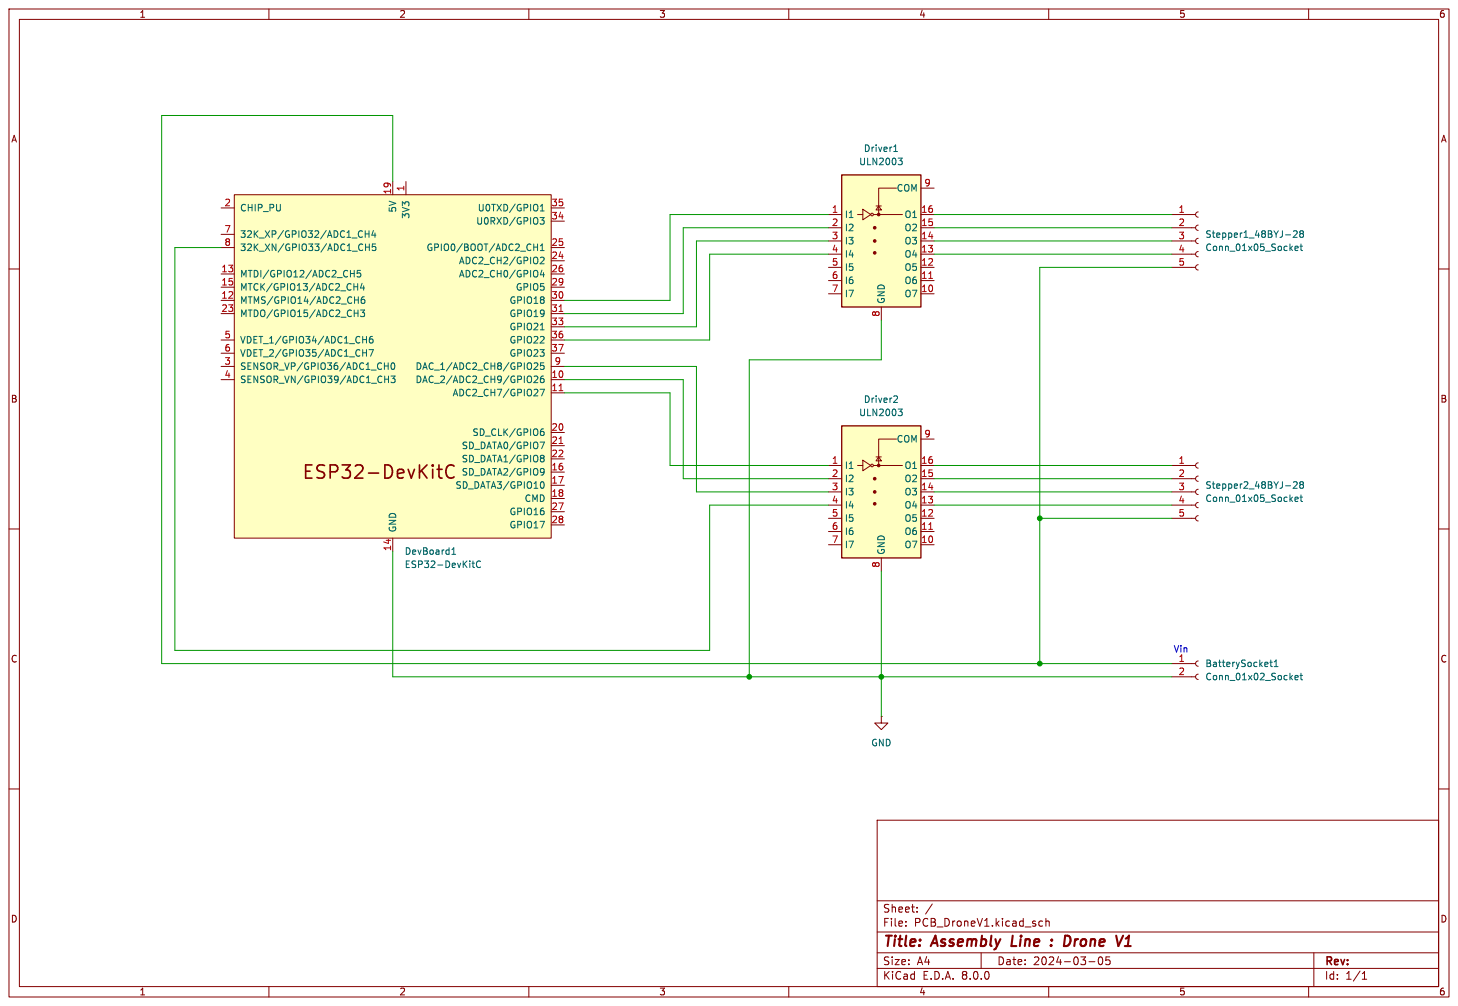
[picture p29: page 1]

1 DAC_2/ADC2_CH9/GPIO26 10 ADC2_CH7/GPIO27 11 MTMS/GPIO14/ADC2_CH6 12 MTDI/GPIO12/ADC2_CH5 13 MTCK/GPIO13/ADC2_CH4 15 SD_DATA2/GPIO9 16 SD_DATA3/GPIO10 17 CMD 18 CHIP_PU 2 SD_CLK/GPIO6 20 SD_DATA0/GPIO7 21 SD_DATA1/GPIO8 22 MTDO/GPIO15/ADC2_CH3 23 ADC2_CH2/GPIO2 24 GPIO0/BOOT/ADC2_CH1 25 ADC2_CH0/GPIO4 26 GPIO16 27 GPIO17 28 GPIO5 29 SENSOR_VP/GPIO36/ADC1_CH0 3 GPIO18 30 GPIO19 31 GPIO21 33 U0RXD/GPIO3 34 U0TXD/GPIO1 35 GPIO22 36 GPIO23 37 SENSOR_VN/GPIO39/ADC1_CH3 4 VDET_1/GPIO34/ADC1_CH6 5 VDET_2/GPIO35/ADC1_CH7 6

File: PCB_DroneV1.kicad_sch Sheet: /
Id: 1/1 Title: Assembly Line : Drone V1

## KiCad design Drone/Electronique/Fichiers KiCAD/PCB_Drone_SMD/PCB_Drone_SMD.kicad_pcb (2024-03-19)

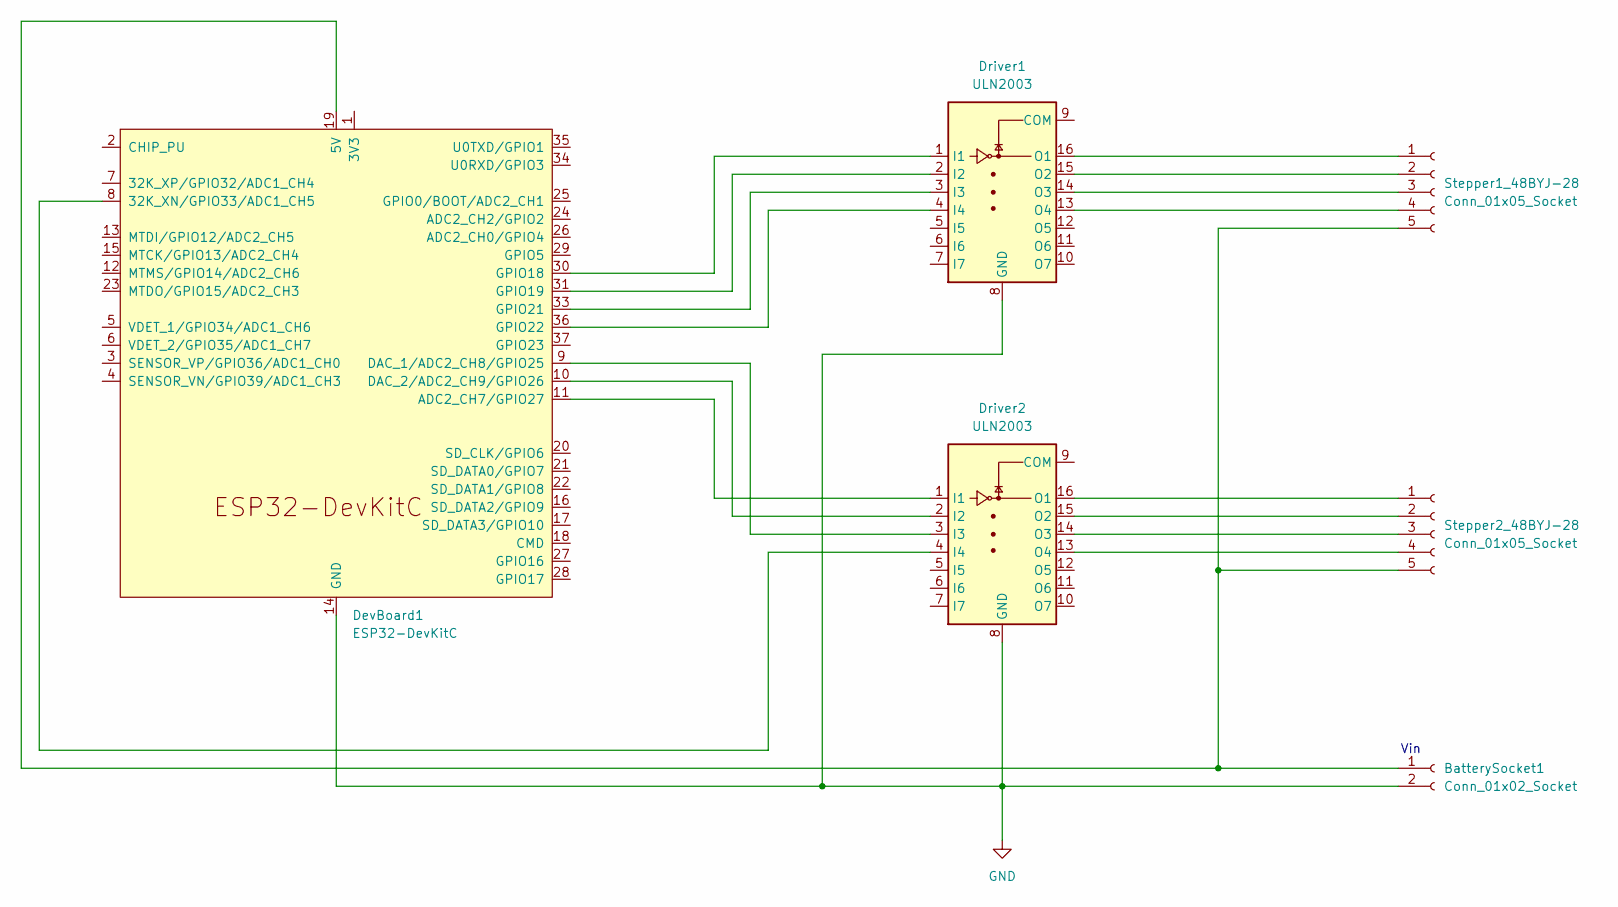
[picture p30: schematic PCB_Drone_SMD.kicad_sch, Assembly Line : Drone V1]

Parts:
BatterySocket1: Conn_01x02_Socket; JST_XH_S2B-XH-A_1x02_P2.50mm_Horizontal
DevBoard1: ESP32-DevKitC
Driver1, Driver2: ULN2003; DIP-16_W7.62mm_SMDSocket_SmallPads
Stepper1_48BYJ-28, Stepper2_48BYJ-28: Conn_01x05_Socket; JST_XH_B5B-XH-A_1x05_P2.50mm_Vertical

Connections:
GND: BatterySocket1.2, DevBoard1.14 (GND), DevBoard1.32 (GND), DevBoard1.38 (GND), Driver1.8 (GND), Driver2.8 (GND)
unnamed: BatterySocket1.1, DevBoard1.19 (5V), Stepper1_48BYJ-28.5, Stepper2_48BYJ-28.5
unnamed: DevBoard1.8 (32K_XN/GPIO33/ADC1_CH5), Driver2.4 (I4)
unnamed: DevBoard1.11 (ADC2_CH7/GPIO27), Driver2.1 (I1)
unnamed: DevBoard1.9 (DAC_1/ADC2_CH8/GPIO25), Driver2.3 (I3)
unnamed: DevBoard1.10 (DAC_2/ADC2_CH9/GPIO26), Driver2.2 (I2)
unnamed: DevBoard1.30 (GPIO18), Driver1.1 (I1)
unnamed: DevBoard1.31 (GPIO19), Driver1.2 (I2)
unnamed: DevBoard1.33 (GPIO21), Driver1.3 (I3)
unnamed: DevBoard1.36 (GPIO22), Driver1.4 (I4)
unnamed: Driver1.16 (O1), Stepper1_48BYJ-28.1
unnamed: Driver1.15 (O2), Stepper1_48BYJ-28.2
unnamed: Driver1.14 (O3), Stepper1_48BYJ-28.3
unnamed: Driver1.13 (O4), Stepper1_48BYJ-28.4
unnamed: Driver2.16 (O1), Stepper2_48BYJ-28.1
unnamed: Driver2.15 (O2), Stepper2_48BYJ-28.2
unnamed: Driver2.14 (O3), Stepper2_48BYJ-28.3
unnamed: Driver2.13 (O4), Stepper2_48BYJ-28.4

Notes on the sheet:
Vin

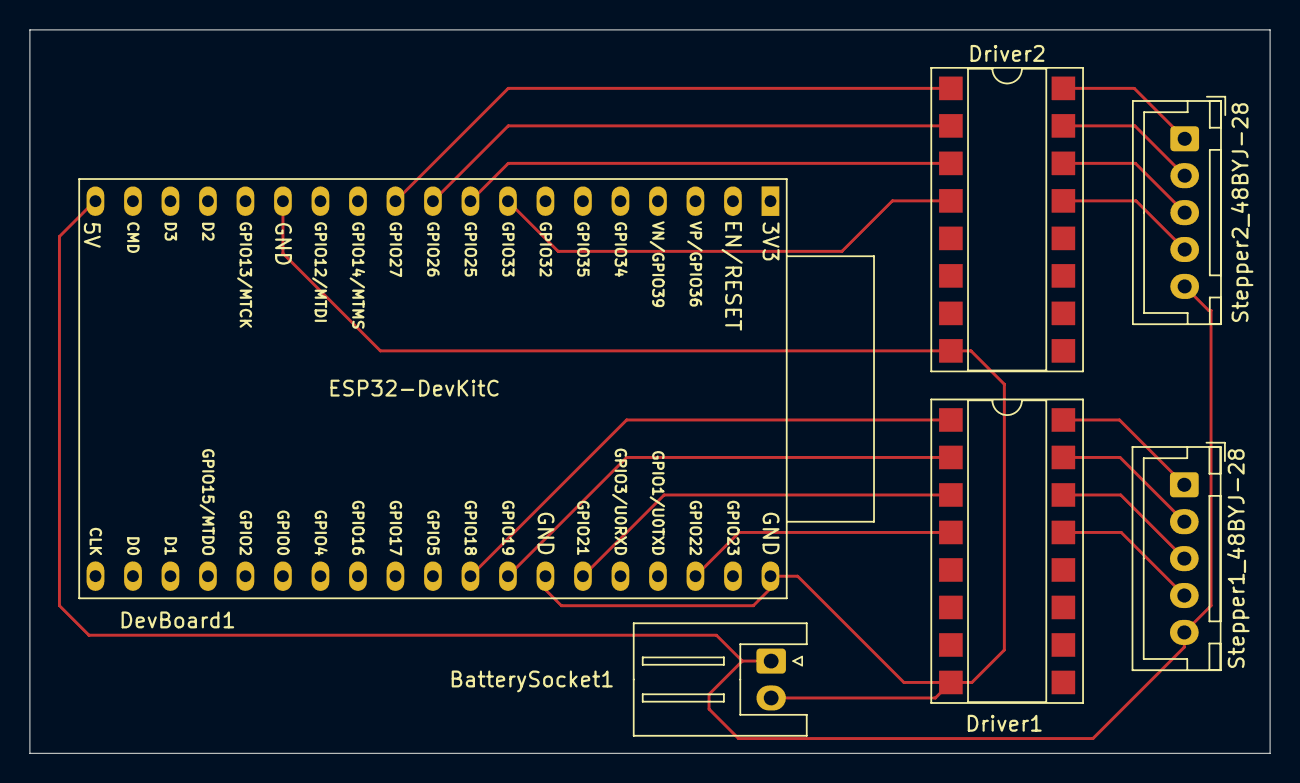
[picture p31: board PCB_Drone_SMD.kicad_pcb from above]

Board: 2 copper layers, 84.0 x 49.0 mm, 6 parts (0 on the bottom side), 18 nets.

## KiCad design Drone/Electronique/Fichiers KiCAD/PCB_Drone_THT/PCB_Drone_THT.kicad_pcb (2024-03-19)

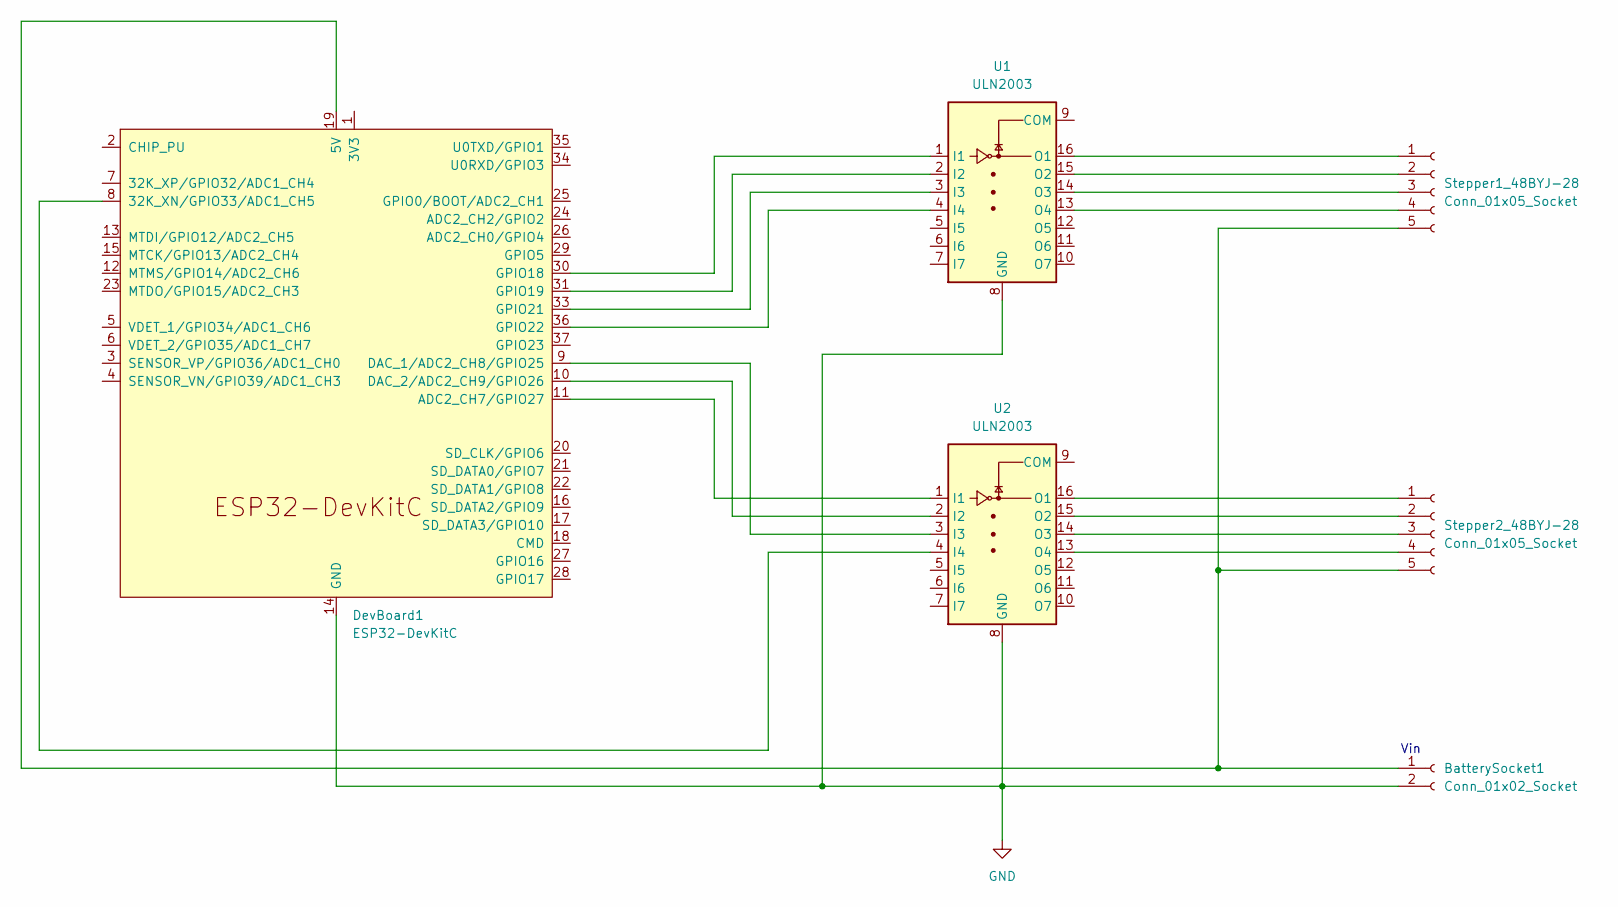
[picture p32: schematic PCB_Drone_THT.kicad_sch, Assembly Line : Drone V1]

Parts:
BatterySocket1: Conn_01x02_Socket; JST_XH_S2B-XH-A_1x02_P2.50mm_Horizontal
DevBoard1: ESP32-DevKitC
Stepper1_48BYJ-28, Stepper2_48BYJ-28: Conn_01x05_Socket; JST_XH_B5B-XH-A_1x05_P2.50mm_Vertical
U1, U2: ULN2003; DIP-16_W7.62mm_Socket_LongPads

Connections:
GND: BatterySocket1.2, DevBoard1.14 (GND), DevBoard1.32 (GND), DevBoard1.38 (GND), U1.8 (GND), U2.8 (GND)
unnamed: BatterySocket1.1, DevBoard1.19 (5V), Stepper1_48BYJ-28.5, Stepper2_48BYJ-28.5
unnamed: DevBoard1.8 (32K_XN/GPIO33/ADC1_CH5), U2.4 (I4)
unnamed: DevBoard1.11 (ADC2_CH7/GPIO27), U2.1 (I1)
unnamed: DevBoard1.9 (DAC_1/ADC2_CH8/GPIO25), U2.3 (I3)
unnamed: DevBoard1.10 (DAC_2/ADC2_CH9/GPIO26), U2.2 (I2)
unnamed: DevBoard1.30 (GPIO18), U1.1 (I1)
unnamed: DevBoard1.31 (GPIO19), U1.2 (I2)
unnamed: DevBoard1.33 (GPIO21), U1.3 (I3)
unnamed: DevBoard1.36 (GPIO22), U1.4 (I4)
unnamed: Stepper1_48BYJ-28.1, U1.16 (O1)
unnamed: Stepper1_48BYJ-28.2, U1.15 (O2)
unnamed: Stepper1_48BYJ-28.3, U1.14 (O3)
unnamed: Stepper1_48BYJ-28.4, U1.13 (O4)
unnamed: Stepper2_48BYJ-28.1, U2.16 (O1)
unnamed: Stepper2_48BYJ-28.2, U2.15 (O2)
unnamed: Stepper2_48BYJ-28.3, U2.14 (O3)
unnamed: Stepper2_48BYJ-28.4, U2.13 (O4)

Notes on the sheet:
Vin

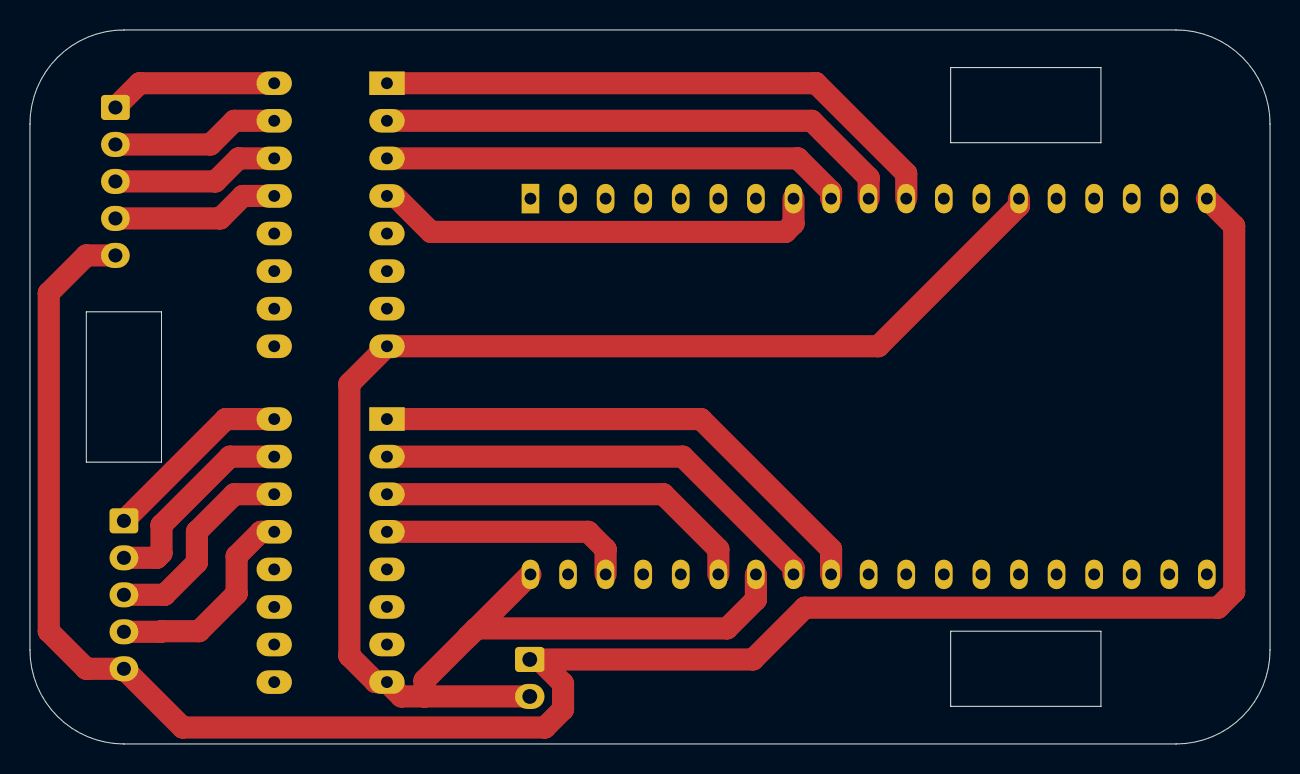
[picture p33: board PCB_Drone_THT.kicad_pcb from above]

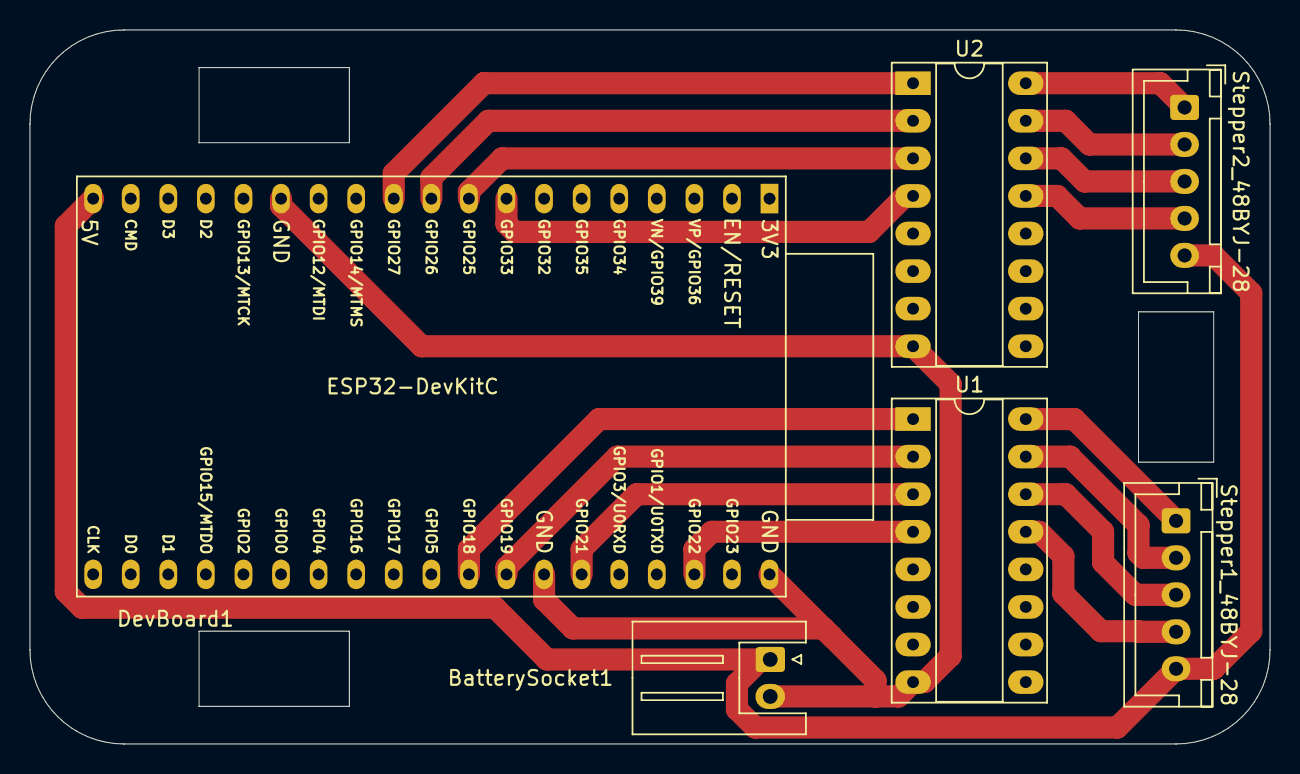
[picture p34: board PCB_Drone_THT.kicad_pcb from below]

Board: 2 copper layers, 83.8 x 48.3 mm, 6 parts (6 on the bottom side), 18 nets.

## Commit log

2024-03-06 Déplacement fichier
    [PCB_DroneV1.kicad_pcb]
2024-03-19 Add fichiers Kicad version THT et SMD
    [PCB_Drone_SMD.kicad_pcb, PCB_Drone_SMD.kicad_sch, PCB_Drone_THT.kicad_pcb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]
